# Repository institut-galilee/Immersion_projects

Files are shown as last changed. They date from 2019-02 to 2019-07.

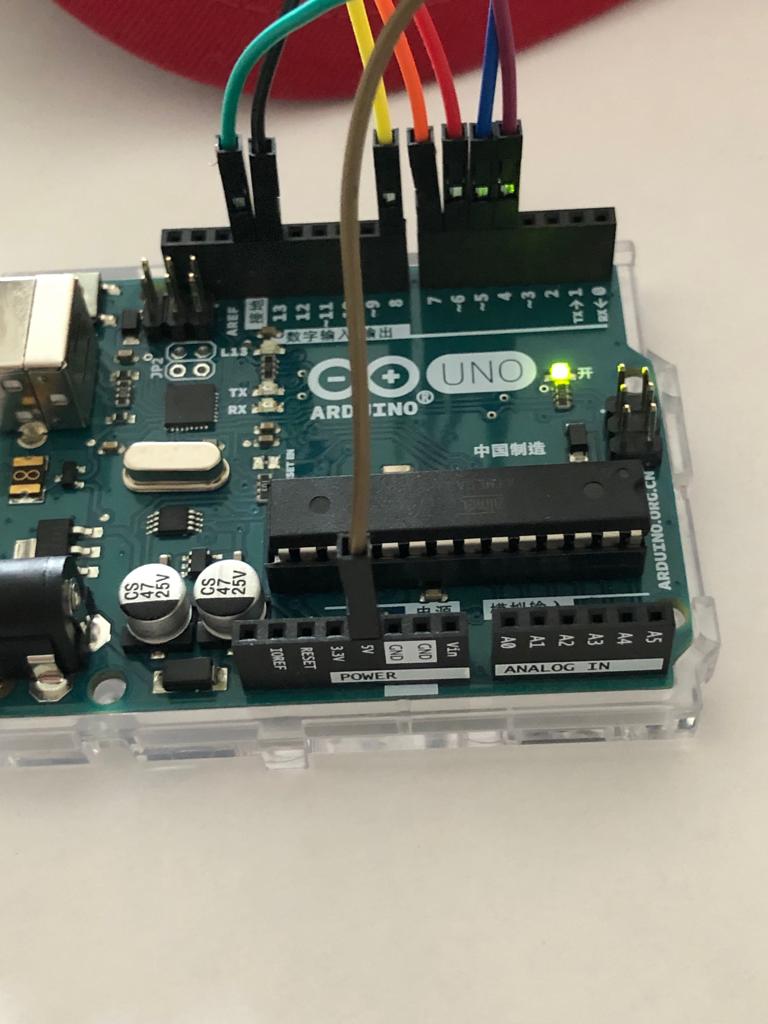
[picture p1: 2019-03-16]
Test Arduino/TCS3200/Montage 3.jpeg

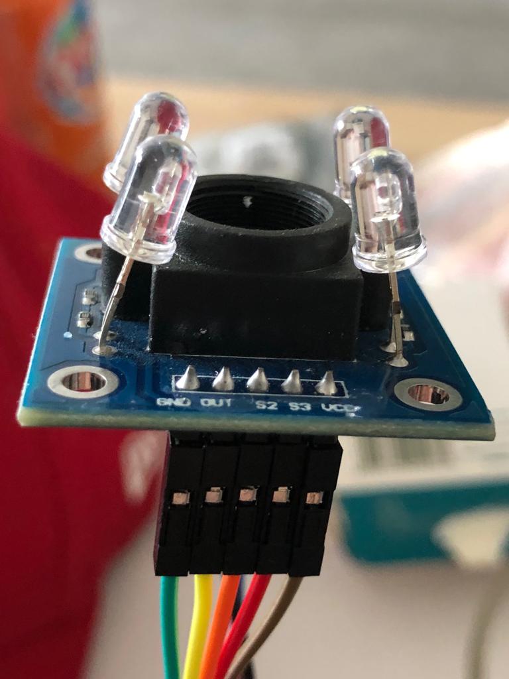
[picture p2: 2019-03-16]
Test Arduino/TCS3200/Montage 1.jpeg

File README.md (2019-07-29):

# Immersion_projects

## MEMBRES DE L'EQUIPE :
* Prenom: Heba Kaddouh [Hebakaddouh](https://github.com/Hebakaddouh)
  Email : heba.kaddouh@gmail.com
	  
* Prenom: Mohamed Ben Saad [Mohaabenz](https://github.com/Mohaabenz)
  Email : bensaad.mohamedamine@gmail.com

* Prenom: Jessy Colombo [Greyman93](https://github.com/Greyman93)
  Email : jessy.colombo31@gmail.com
	  
* Prenom: Khalid Barakat [Giitto](https://github.com/Giitto)
  Email : bckhalid@hotmail.fr
	  
## Nom du produit : Set-up Immersion 3.5D;

## Idée de base :

Le but de notre produit est une immersion dans une expérience multimédia s'approchant de la technologie de la 4DX à moindre coût.
Pour cela nous devons créer un set-up adaptable sur toutes les structures (télévisions, ordinateurs...). Le set-up est composé de la façon suivante :	
	
* LED : 
Il s'agit d'une bande LED connectée à votre smartphone en bluetooth que vous pourrez contrôler à votre guise. 
Mais la particularité de cette bande est son mode immersif : Elle s'adaptera automatiquement aux couleurs prédominantes,
que ce soit pour un jeu video, un film ou juste une image, l'expérience est garantie. 

* Fauteuil : 
Pour le moment, il s'agit d'une évolution du set-up qui permettrait une meilleure immersion quelque soit l'action. 
Pour cela deux enceintes connectées à votre périphérique en bluetooth ou en filaire ammeneront le son au plus proche de soit. 
Aux cotées de ces enceintes, nous allons intégrer des capteurs sonores liés à notre ESP32 qui permettront d'analyser le son. 
	Après analyse, des vibrations seront activé en fonction de l'action. Par exemple, si le bruit d'un balle de pistolet est entendu, 
	les moteurs vibrants situés sur le dos de la chaise s'activeronts. 

* Application : 
	L'application permettra de contrôler la bande LED. Elle pourra allumer ou éteindre la bande, activer les differents modes de 
celle-ci, augmenter ou diminuer la lumière ou bien changer la couleur de la bande.

En fonction de l'avancement du projet, nous pourrons ajouter d'autres amélioration, options, composant et objets connectés sur notre set-up

#### Composants suggerés :
Au départ, nous avons imaginé le set-up avec des composants facilement trouvable, manipulable et programmable.
* LED : ESP32, BANDE LED adressable, Capteurs couleur de lumière, cable USB, kit de connection (fil) ;
* Fauteuil : housse massage ou moteurs vibrants, enceinte bluetooth, ESP32, capteurs sonores; 

## TRAVAIL RÉALISÉ

### Analyse de l'éxistant
Au cours de notre analyse, nous avons pris connaissance de la plupart des technologies se rapprochant de nos objectifs. Pour la LED, les principales technologies sont intégré à l’intérieur même d'un téléviseur et d'autres si y connecte via HDMI ou USB. Toutes les recherches effectuées, nous ont amenés à la conclusion que notre méthode n'a pas encore été exploré. Il s'agit donc d'un défi que nous nous sommes fixé de réaliser. Le fauteuil quant à lui serait une version à moindre coût de la 4DX.

### Conception du prototype

#### LED
La conception de la LED a connu 3 versions :
* Version Alpha : Sur l'ESP32 les bibliothèques n’étaient pas compatibles nous sommes donc passé à l’Arduino pour avoir un prototype rapidement. Une fois la migration faite, la LED est capable de reconnaître les couleurs avec une reproduction approximative. 

* Version Beta : Le calibrage des couleurs est intégré afin de reproduire le plus fidèlement possible ce qui est émis par n'importe quel écran LED ou LCD (d'autres test pourront permettre une adaptation polyvalente).

* Version proto : Un ajout du Bluetooth liant application et micro-contrôleur afin de faciliter l'expérience utilisateur.  

#### Application

La conception de l'application a connu 2 versions :

* Version 0.1 : Une interface simple permettant de contrôler les couleurs de la LED via Bluetooth.

* Version 0.2 : Ajout d'une interface permettant le calibrage du capteur directement via l'application en suivant des intructions détaillées. Création de théme comme fondue, gradiant et guirlande.

### Perspectives

* La conception d'un fauteuil qui est encore en cours

* Passage à l'ESP32 qui serait un gain en coût, énergie et de taille.

* Permettre à l'utilisateur de mettre à jour son micro-contrôleur directement à partir de l'application

* Création d'un prototype ergonomique, compacte et facile d'installation.

* Création de trois modèles à budgets différents. Un modèle composé d'un capteur pour une immersion se basant sur la couleur prédominante. Un second avec quatre capteurs permettant une immersion plus poussée utilisant l'adressabilité de la LED et reproduisant les couleurs des coins de l’écran. Un dernier composé de tout les capteur nécessaire a l'immersion reproduisant les couleurs point à point.

* Une meilleure interface de l'application

* Rendre la calibration plus accessible à l'utilisateur

* D'autres objets garantissant une immersion toujours plus poussée

* Connecter l'ensemble du set-up à un assistant vocal

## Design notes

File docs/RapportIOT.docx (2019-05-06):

# Développement d’un objet connecté

# Immersion 3.5D

Réalisé par

KADDOUH Heba – BENSAAD Mohamed – COLOMBO Jessy – BARAKAT Khalid

Encadré par

M. Aomar OSMANI & M. Hamidi MASSINISSA

Master 1 Informatique – IOT Année 2018/2019

# Remerciements

Avant tout développement, nous profitons de ce rapport pour remercier ceux qui nous ont beaucoup appris et ceux qui ont eu la gentillesse de faire de cette expérience un moment profitable.

Nous tenons tout d’abord à remercier Monsieur Aomar OSMANI, qui nous a aidé et encadré tout au long du projet avec beaucoup de patience et de pédagogie. Ainsi que Monsieur Hamidi MASSINISSA, qui est resté disponible pour toutes nos questions et qui a su nous conseiller sur nos différents choix ainsi que sur la méthodologie à prendre.

# Présentation générale

## Présentation de notre application

Le but de notre produit est une immersion dans une expérience multimédia s'approchant de la technologie de la 4DX à moindre coût. Pour cela nous devons créer un set-up adaptable sur toutes les structures (télévisions, ordinateurs...). Le set-up est composé de la façon suivante :

- LED : Il s'agit d'une bande LED connectée à votre smartphone en Bluetooth que vous pourrez contrôler à votre guise. Mais la particularité de cette bande est son mode immersif : Elle s'adaptera automatiquement aux couleurs prédominantes, que ce soit pour un jeu vidéo, un film ou juste une image, l'expérience est garantie.
- Application : L'application permettra de contrôler la bande LED. Elle pourra allumer ou éteindre la bande, activer les différents modes de celle-ci, augmenter ou diminuer la lumière ou bien changer la couleur de la bande.
- Fauteuil : Pour le moment, il s'agit d'une évolution du set-up qui permettrait une meilleure immersion quel que soit l'action. Pour cela deux enceintes connectées à votre périphérique en Bluetooth ou en filaire amèneront le son au plus proche de soi. Aux cotées de ces enceintes, nous allons intégrer des capteurs sonores liés à notre ESP32 qui permettront d'analyser le son. Après analyse, des vibrations seront activé en fonction de l'action. Par exemple, si le bruit d’une balle de pistolet est entendu, les moteurs vibrants situés sur le dos de la chaise s'activeront.

La finalité du projet est la création d’un prototype fonctionnel pouvant par la suite s’améliorer avec de plus grands moyens financier et une focalisation exclusif sur celui-ci.

## Les enjeux

L’enjeu du projet qui nous a donné la motivation de le réaliser est d’ajouter une touche d’immersion dans le visionnage de diverses multimédias.

# Besoin de notre projet

Dans notre cahier de charges on a défini les besoins comme suite :

### LEDs connectées

Fonction | S’accorder en fonction de la couleur de l’écran TV
Objectif | S’éclairer de la couleur dominante de l’écran
Description | La bande LED sera munie d’un capteur de lumière qui lui transmettra les couleurs de l’écran afin qu’elle change de couleur
Contraintes | Le capteur de lumière doit être placé correctement par rapport à l’écran
Niveau de priorité | Haut

Fonction | S’accorder en fonction des couleurs définies par l’utilisateur
Objectif | S’éclairer de la couleur choisie par l’utilisateur
Description | La bande LED sera connectée à l’application et devra changer de couleur en fonction de ce qui est sélectionné dans l’application.
Contraintes
Niveau de priorité | Haut

### Application mobile

Fonction | Se connecter au périphérique
Objectif | Pouvoir contrôler la bande LED
Description | Le téléphone sera connecté en Bluetooth à la bande LED
Contraintes | La distance entre les deux objets connectés doit être raisonnable
Niveau de priorité | Haut

Fonction | Contrôler la bande LED à distance
Objectif | Permettre à l’utilisateur de changer la couleur de la bande
Description | L’application permettra de changer de couleur, allumer et éteindre les LEDs
Contraintes | L’application doit avoir la priorité sur le capteur de lumière
Niveau de priorité | Haut

### Housse connectée

Fonction | Capter le son de la TV
Objectif | Récupérer le signal sonore délivré par le son de la TV
Description | Le fauteuil récupérera le son
Contraintes | Nuisances sonores
Niveau de priorité | Moyen

Fonction | Réagir en fonction du son
Objectif | La housse devra vibrer en fonction de l’intensité du son
Description | Des moteurs vibrants intégrés à la housse réagiront en fonction du son
Contraintes
Niveau de priorité | Haut

# Conception architecturale

## Choix des langages de programmations

Notre application mobile est codée en JAVA pour les activités et classes, et en XML pour le design. Pour cela nous utilisons Android Studio.

Pour l’Arduino et le capteur, nous utilisons du C++ (.ino) à l’aide du logiciel Arduino IDE.

## Maquette de notre application

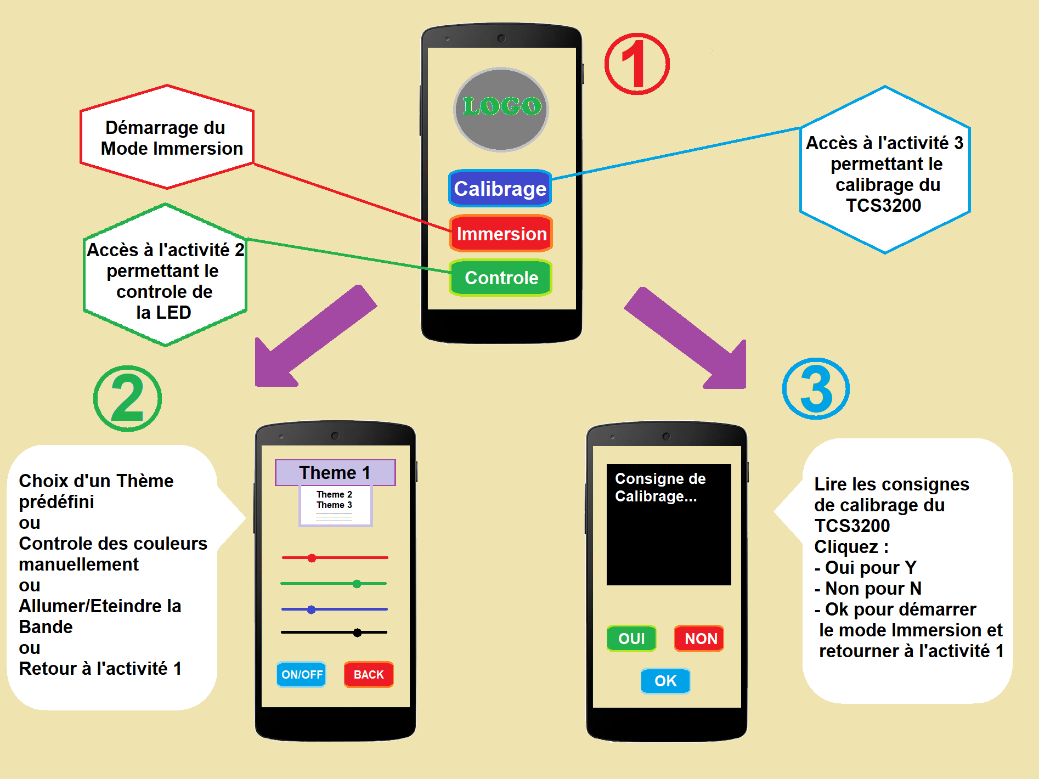
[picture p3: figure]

## Diagramme des cas d’utilisation

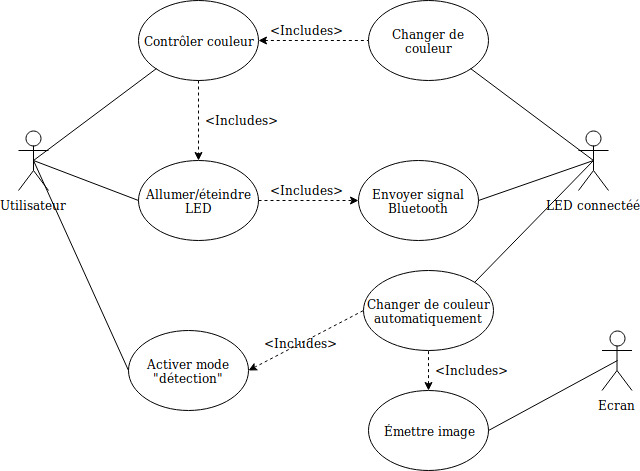
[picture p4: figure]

Un utilisateur pourra donc allumer et éteindre la LED, contrôler les couleurs seulement si la LED est allumée et activer le mode « détection » comportant son calibrage.

# Gestion de projet

## Planification et environnement de travail

Afin de réussir le projet et respecter la date du rendu, il nous a fallu une très bonne gestion et pour cela nous avons opté pour deux méthodes :

La première est l’organisation des membres de l’équipe, d’où le choix d’un chef de projet (Mohamed BEN SAAD), d’une équipe pour l’application mobile (Heba KADDOUH & Jessy COLOMBO) et d’une autre pour l’Arduino (Mohamed BEN SAAD & Khalid BARAKAT). Pour faciliter la communication nous avons créé un groupe WhatsApp qui nous permettait d’organiser des réunions (le jeudi matin ainsi que les mardis à 17h00 après le cours d’IOT, sans oublier, les créneaux du module), de s’entraider, de faire un échange d’informations et de faire une mise au point.

De plus, notre chargé de TD nous a conseillé de créer un compte GitHub afin de pouvoir suivre toutes les modifications du code et y avoir accès en cas de problème technique, que nous avons utilisé sans modération.

Nous avons mis en place sur GitHub dans l’onglet Projects, un planificateur de toutes les tâches que nous allons accomplir, que nous avons accomplies et que nous sommes en train d’accomplir. Ce planificateur nous a permis de se retrouver et de voir ce qu’il restait à faire. On peut aussi y retrouver les liens utiles, les composants et les logiciels utilisés.

## Répartition des tâches

Comme nous l’avons dans la partie précédente, nous avons réparti le travail en deux équipes.

Nous avons tous contribué à la conception architecturale en réalisant le diagramme de Gantt et du cas d’utilisation qu’on peut retrouver sur le GitHub, ainsi qu’à la rédaction du cahier des charges, de l’étude de l’existant, du rapport et de la conception du diaporama de présentation.

Pour avoir un meilleur aperçu du temps accordé pour chaque tâche, nous avons réalisé deux diagrammes : pour l’application mobile et pour l’Arduino.

## Diagramme de Gantt

Le diagramme de GANTT est un outil efficace permettant de générer une visualisation de l’avancement du projet. Il permet de donner une vue globale des tâches à réaliser et le du temps associé.

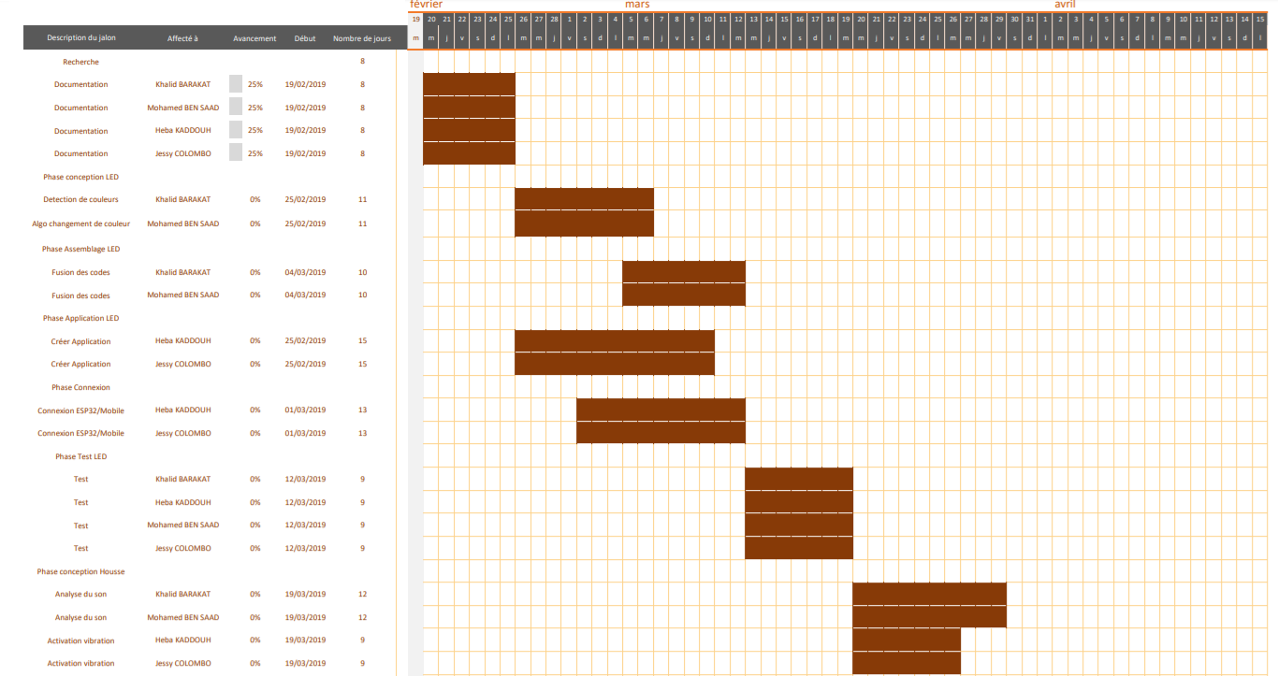
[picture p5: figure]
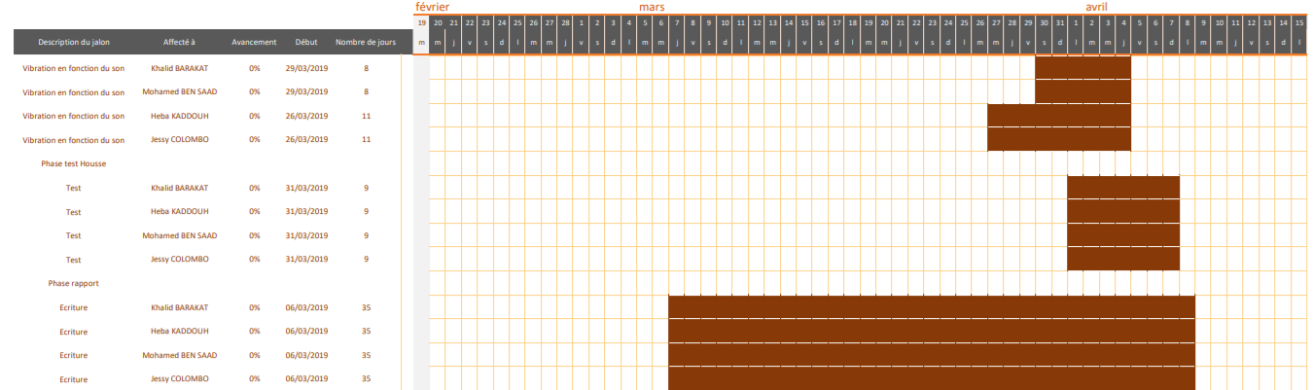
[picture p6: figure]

Nous avons réalisé le diagramme de Gant dans l’optique de l’accomplissement total du projet. Sauf que nous avions sous-estimé la complexité de celui-ci. Nous détaillerons tous nos changements par la suite.

# Développement du Set-Up

## Arduino

Au départ nous avons décidé d’utiliser une ESP32 pour notre projet. Malheureusement, après plusieurs essais de couplage de celle-ci avec notre capteur TCS3200, nous avons remarqué que l’architecture de l’ESP32 n’était pas compatible. Il aura fallu tout implémenter nous même pour l’adapter avec le capteur. Nous avons donc jugé plus judicieux de passer à une Arduino vu le temps qui nous était imparti. Ce choix n’a pas été anodin car nous avons trouvé plusieurs codes fonctionnels sur Arduino. Cela nous a permis de comprendre et de nous familiariser avec le TCS3200.

### Capteur TCS3200

Ces capteurs sont conçus pour détecter les couleurs d’objets et non celles d’un écran. Nous avons fait un pari risqué en le choisissant car nous ne savions pas s’il répondrait à nos attentes. Son faible prix nous a aidé à sauter le pas, nous réconfortant sur la faible perte qu’il aurait pu présenter.

Face droite Face Avant Face Gauche

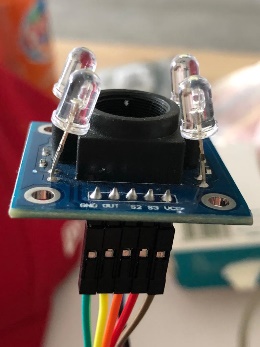
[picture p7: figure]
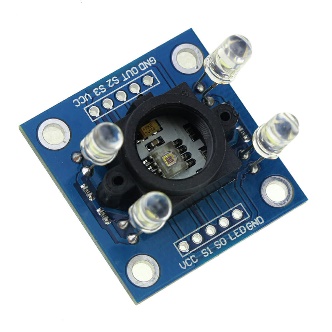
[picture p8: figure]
RÃ©sultat de recherche d'images pour "TCS3200"
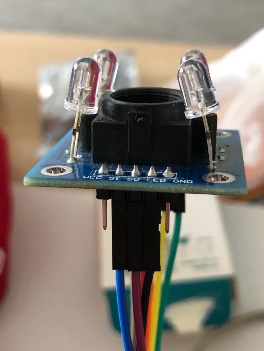
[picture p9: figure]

Notre premier objectif a été de faire fonctionner notre capteur avec l’Arduino. Le branchement a été rapidement maîtrisé grâce à quelques exemples trouvés au préalable.

Un fois le montage opérationnel, nous avons testé notre capteur avec plusieurs codes comme celui fourni avec le manuel électronique du TCS3200 et d’autres trouvés sur le Web. Cependant, comme le capteur n’est pas destiné aux écrans, la plupart de nos tests ont malheureusement échoué. À ce stade, nous avons réussi à reconnaitre les couleurs primaires (rouge, vert et bleu) avec des valeurs non conformes à nos attentes allant de -10 000 à 10 000. Nous devions remédier à ce problème et trouver une fonction qui nous permettrait de calibrer le capteur sur tous types d’écrans ainsi que de ramener les valeurs reçues entre 0 et 255. Nous avons essayé plusieurs modèles mathématiques pour moduler les valeurs captées, mais les codes utilisés n’étaient toujours pas dans l’intervalle voulu pour notre projet.

Après de nouvelles recherches, nous avons découvert une bibliothèque sur GitHub : https://github.com/blascarr/TCS3200-ColorSensor avec « TSC3200.h », implémenté spécialement pour le modèle de capteur que nous utilisons, incluant une fonction de calibrage optimal. Nous avons analysé cette bibliothèque pour pouvoir la modifier et l’adapter à nos nécessités. Une fois accordée à nos besoins, le résultat a répondu à toutes nos espérances. Pour calibrer le TCS3200, il suffit juste de poser le capteur sur l’écran avec la suite de couleur demandées lors de l’exécution de la fonction « calibration() ». Toutes les instructions sont affichées sur le Serial de l’Arduino (Terminal). Cependant, une source de lumière externe peut fausser celui-ci.

Par la suite, nous avons intégré la bande LED « Pixel Strip » à l’Arduino. A l’aide de sa bibliothèque originale « Adafruit_NeoPixel.h », nous avons pu lui envoyer les valeurs perçues par le capteur. Après quelques optimisations sur la synchronisation entre le TCS3200, l’Arduino et la bande LED, le Mode Immersion venait de voir le jour.

### Bluetooth HC-05

Le choix du HC-05 a été fait en fonction de son prix, de sa popularité et de sa bonne notation. À priori l’achat était sûr.

Il existe deux types de branchements, l’un est pour faire communiquer l’Arduino avec un autre objet connecté, le deuxième sert à paramétrer le module Bluetooth, par exemple donner un nouveau nom au HC-05 pour mieux l’identifier.

Branchement avec KEY pour configurer le Bluetooth

Pour vérifier que tout fonctionne comme il faut, il envoie « AT » vers l’Arduino. Si on obtient la réponse « OK », alors tout fonctionne et maintenant on peut utiliser les commandes de l’AT-MODE. Pour renommer le Bluetooth on rentre maintenant la commande AT-NAME = <nouveau_nom>.

Branchement normal pour communication

On envoie les données sur les ports TX/RX de l’Arduino. Cela facilité l’implémentation du code car il n’est plus nécessaire d’ouvrir un nouveau Serial pour transférer des données. Il faut noter que le TX du HC-05 se branche sur le RX de l’Arduino et le RX sur le TX. La communication est très importante pour le calibrage du TCS3200, étant donné que chaque modèle d’écran a des caractéristiques de couleur et de luminosité différente. Il faut bien suivre les instructions lors du calibrage du capteur pour ne pas avoir des erreurs sur les couleurs affichées ou leur intensité.

## Montage final

Une fois les deux parties précédentes accomplies, nous avons assemblé toutes les fonctionnalités dans un même code pouvant contrôler tous les composants de notre objet connecté ainsi que de toutes nouvelles fonctionnalités. C’est-à-dire, la communication Android/Arduino, le contrôle de la bande Led manuellement et les différents modes de celui-ci.

Voici le montage final de celui-ci :

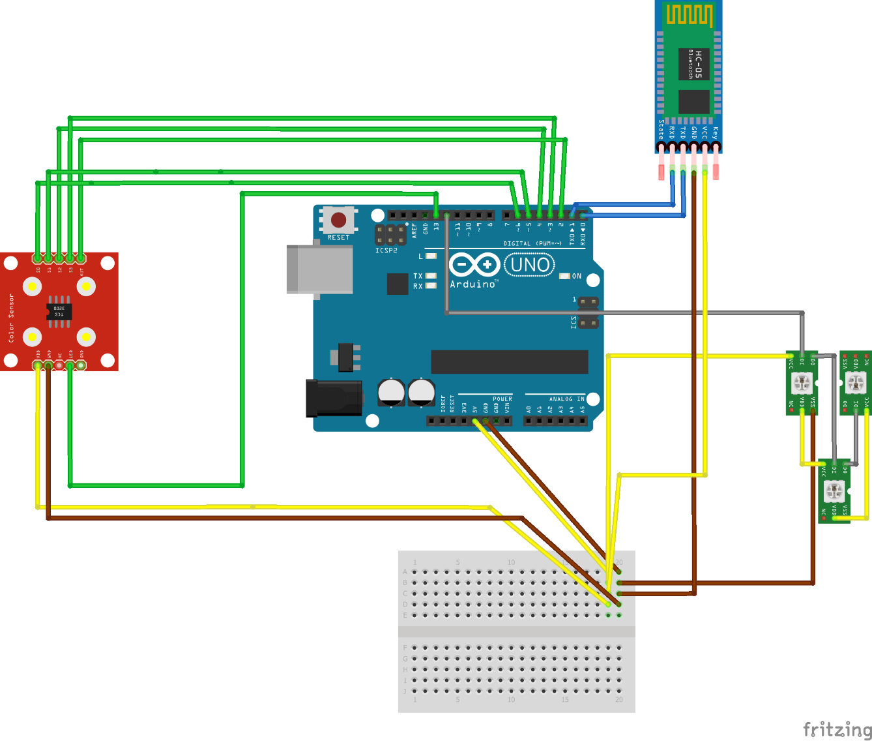
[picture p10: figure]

Composants | Port objet | Port Arduino
TCS3200 | VCC | 5V
| S3 | 3
| S2 | 4
| OUT | 2
| GND | GND
| S1 | 5
| S0 | 6
| LED | 13
HC-05 | GND | GND
| VCC | 5V
| RXD | TX 1
| TX | RX 0
LED | 5V | 5V
| GND | GND
| Din | 12

## Application mobile

### Page d’accueil

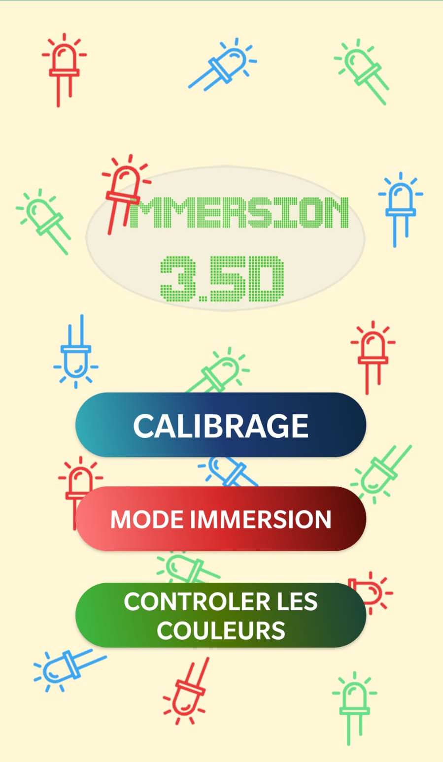
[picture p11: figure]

Lorsque l’utilisateur lance l’application, il se retrouve sur cette page et une connexion BluetoothSocket (bSocket) est lancée. La connexion Bluetooth est établie grâce à notre fonction « bluetooth_connect_device()». Si la connexion n’est pas établie, une fenêtre pop-up s’affiche « Vous n'êtes pas connecté avec l’équipement » et l’interface ne peut pas être utilisée. Et si la connexion Bluetooth n’est pas activée alors une demande d’activation de Bluetooth est demandé.

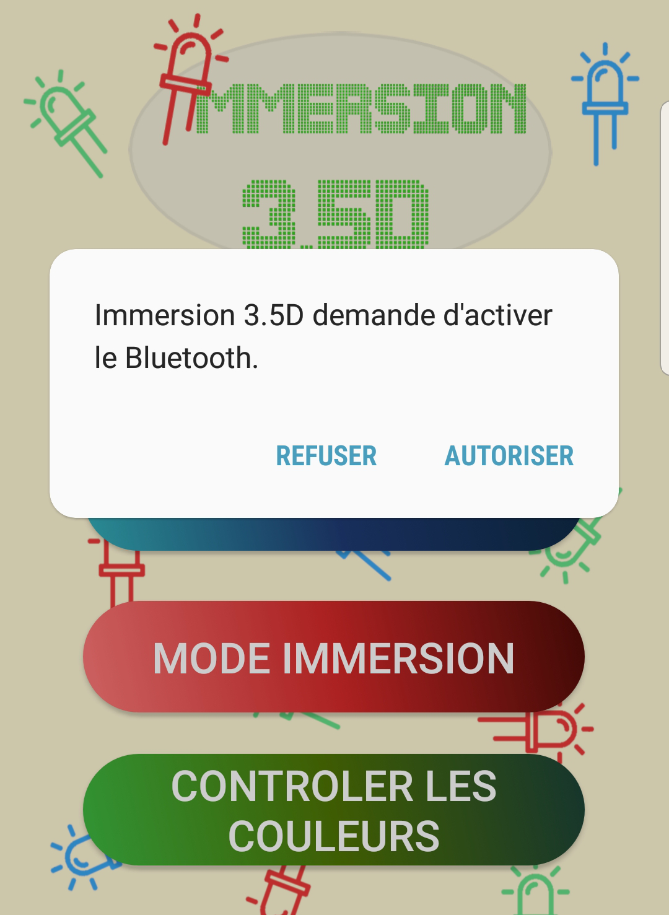
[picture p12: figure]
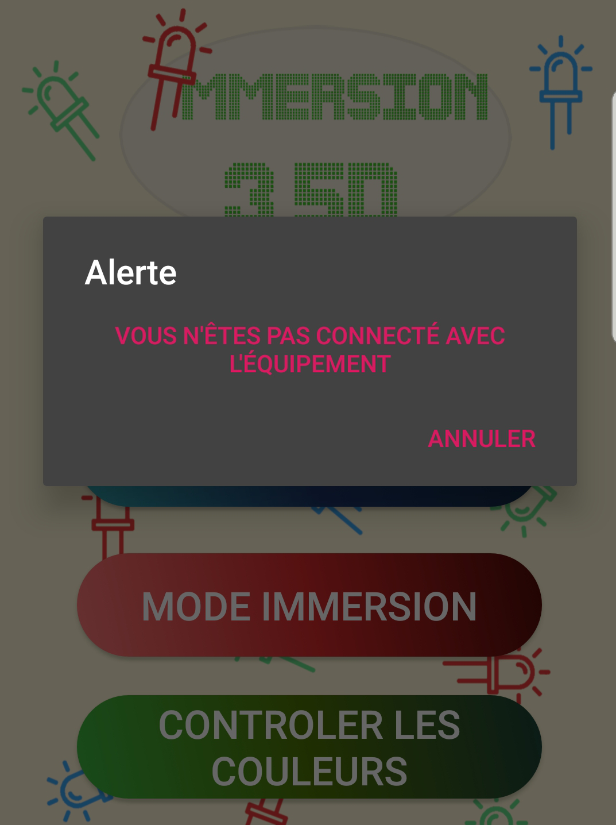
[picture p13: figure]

Au lancement de l’application, on envoie la lettre « O » par Bluetooth à l’Arduino qui permet de la mettre en mode On/Off.

A partir de cette page l’utilisateur peut, au click :

- Calibrer le TCS3200, en envoyant la lettre « C » par Bluetooth à l’Arduino et passe à la page de calibrage.
- Entrer en mode immersion en envoyant la lettre « I » par Bluetooth à l’Arduino et passe en mode immersion tout en restant sur cette page.
- Contrôler les couleurs en envoyant la lettre « T » par Bluetooth à l’Arduino et passe à l’interface de contrôle de la bande de leds.

L’envoi de caractères à l’Arduino via Bluetooth se fait comme suit : « bSocket.getOutputStream().write("O".getBytes()); »

### Page de calibrage

Lorsque l’on sélectionne le mode « calibrage », nous avons un champ de texte qui contient tout ce qui est renvoyé par l’Arduino et trois boutons :

- Oui, qui envoie la lettre « Y » à l’Arduino
- Non, qui envoie la lettre « N » à l’Arduino
- Mode immersion, qui envoie la lettre « O » à l’Arduino

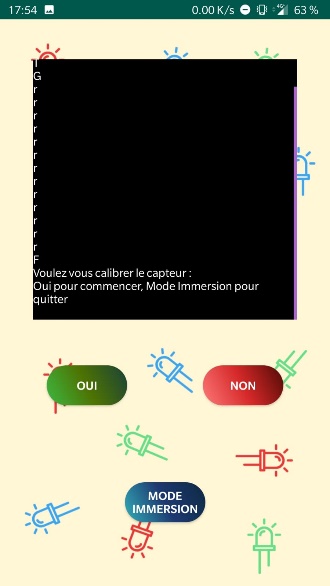
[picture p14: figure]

L’une des difficultés que nous avons eues avec cette page est de lire les données envoyées par l’Arduino. Pour pallier ce problème nous avons décidé de faire un thread qui reçoit, en continu et parallèlement du onCreate, les données grâce à la socket « bSocket » définie dans la page précédente. On dispose d’une boucle while permettant de lire les données envoyées par l’Arduino et de les afficher dans le champ de texte.

### Page de contrôle

En appuyant sur le bouton « contrôler les couleurs » depuis la page d’accueil, la page se transforme en un panneau de contrôle (représenté ci-dessous) contenant trois jauges pour configurer les couleurs selon le rouge, le vert et le bleu, et une quatrième jauge pour régler la luminosité. Grâce à la fonction « onProgressChanged », à chaque fois que l’utilisateur déplace un curseur nous stockons la valeur de la jauge que nous envoyons à l’Arduino.

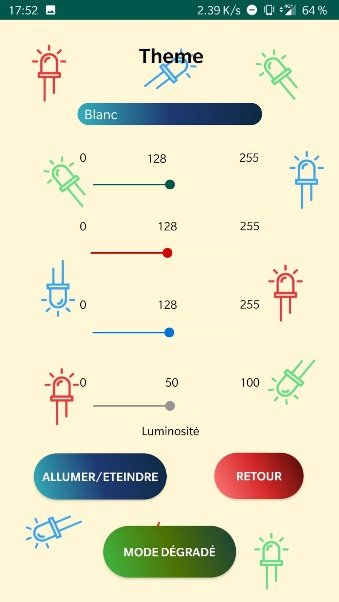
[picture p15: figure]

L’utilisateur a la possibilité de sélectionner des couleurs prédéfinies dans le menu déroulant se situant en haut de l’écran.

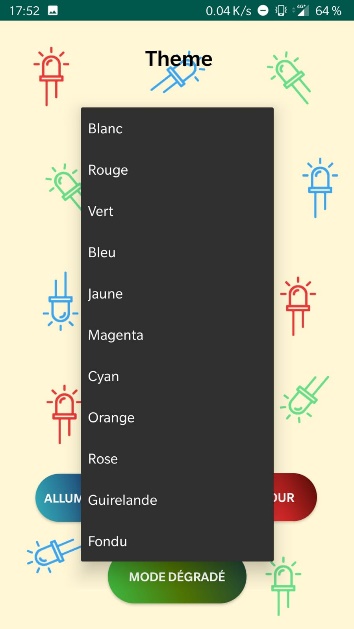
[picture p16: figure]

Lorsque l’utilisateur sélectionne un thème un caractère est envoyé à l’Arduino afin qu’il différencie les différents thèmes. Lorsque le thème « Guirlande » ou « Fondu » est activé, les jauges se désactivent. Pour chaque thème, on envoie le caractère « T » suivi des valeurs des couleurs sauf pour «Guirlande » et « fondu » :

- « G » pour guirlande
- « F » pour fondu

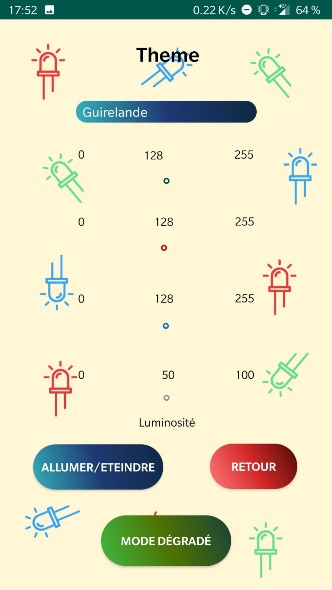
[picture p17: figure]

L’interface dispose également de trois boutons : « allumer/éteindre » pour allumer ou éteindre la bande de LEDS, « retour » pour revenir à la page d’accueil et « mode dégradé » menant à un nouveau panneau de contrôle servant cette fois-ci à configurer deux couleurs pour en faire le dégradé.

Là aussi des caractères spécifiques sont envoyés pour chaque bouton :

- « A » pour allumer
- « E » pour éteindre
- « D » pour le mode dégradé

### Mode dégradé

Le mode dégradé offre la possibilité de choisir deux couleurs, permettant ensuite à la bande de LEDS de s’illuminer du dégradé de la couleur n°1 à la couleur n°2. Comme pour la page précédente, on envoie les couleurs des différentes jauges ainsi que la luminosité à l’Arduino.

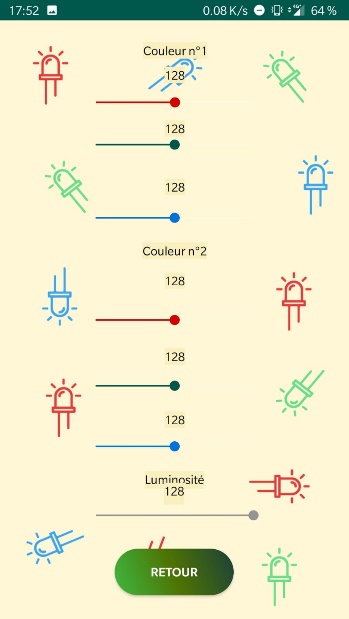
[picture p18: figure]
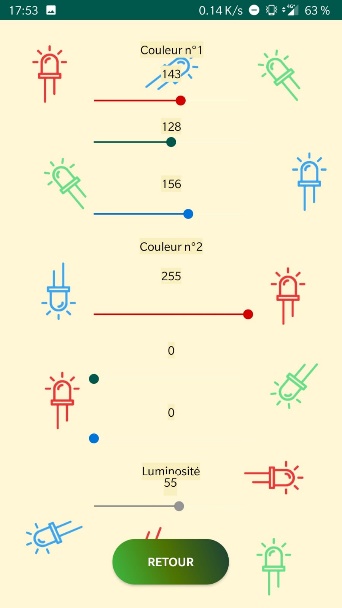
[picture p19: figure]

## Logo

Pour réaliser ce logo nous avons utilisé Paint3D.

# Contraintes/Difficultés

Choix de la carte électronique : Nous avons au début opté pour une ESP32 qui n’était pas compatible avec l’architecture de notre capteur.

Contraintes du capteur : environnement sombre et avoir juste l’écran comme source de lumières

Lecture et écriture de données : Nous avons eu du mal à :

- Lire les données envoyer par l’Arduino
- Envoyer des données à l’Arduino

Au vu de la complexité du projet et le manque de temps lié aux autres cours et projets, nous n’avons pas pu réaliser le fauteuil qui était une extension de notre projet.

# Bilan du projet

Ce projet était d’une grande envergure sur l’aspect fonctionnel et structurel mais il a été formateur et enrichissant pour nous, en effet l’idée du projet était assez compliquée et pour la mettre en œuvre il nous a fallu beaucoup de recherche et de persévérance. On a pu s’auto former sur les différents langages utilisés et mettre en pratique nos précédentes connaissances comme UML pour réaliser les différents diagrammes de conception. Ce projet était aussi une occasion de découvrir le vrai travail d’équipe.

# Annexe

## Mode d’emploi

Pour utiliser l’application, l’utilisateur doit d’abord appairer en Bluetooth son smartphone Android à l’Arduino. Une fois connecté il pourra effectuer les actions suivantes :

- Calibrer
- Contrôler les couleurs
- Lancer le mode automatique

Lorsque l’utilisateur clique sur « Calibrage », il reçoit une demande de confirmation. Si l’utilisateur clique sur « non », l’Arduino va charger les réglages stockés dans la mémoire. En revanche si l’utilisateur appuie sur le bouton « oui », le calibrage rapide commence, il faut alors mettre le capteur sur du Blanc et du Gris. En effet les écrans émettant toujours de la lumière. Le noir ne sera jamais vraiment noir donc un gris sombre est alors le meilleur choix. A chaque étape, une confirmation de l’utilisateur est requise dans le cas où il n’était pas prêt à capturer la couleur demandée. Une fois cela fait, un message s’affiche demandant à l’utilisateur s’il veut remplacer les réglages par défaut par la capture qui vient d’être effectuée. Pour finir la première étape, un nouveau message s’affiche demandant si l’utilisateur veut aussi calibrer les couleurs. S’il appuie sur « non », le calibrage prend fin et affiche les valeurs enregistrées. A l’opposé si l’utilisateur lance la deuxième étape, des indications vont s’afficher pour calibrer sur les couleurs suivantes : bleu, jaune, marron, orange, rouge et vert, en suivant la même procédure que lors de la première étape. Pour terminer, un dernier message demande si l’utilisateur veut sauvegarder le calibrage dans la mémoire. Une fois la réponse reçue, sur le terminal sont affichées les valeurs capturées de chaque couleur lors du calibrage. Les valeurs affichés pour une couleur sont d’abord le rouge puis le vert puis le bleu et enfin la luminosité.

Pour un bon calibrage voici une table avec les intervalles de valeurs à obtenir pour chaque couleur :

| Rouge | Vert | Bleu
Blanc | > 250 | > 250 | > 250
Noir | < 15 | < 15 | < 15
Jaune | > 245 | > 245 | < 30
Orange | > 220 | 100 - 200 | < 75
Rouge | > 220 | < 40 | < 40
Vert | < 40 | > 220 | < 40
Bleu | < 40 | < 40 | > 220
Marron | 100 - 180 | < 90 | < 10

Lorsque l’utilisateur clique sur « Mode immersion », la bande LED change de couleur en fonction de celle perçue par le capteur. L’utilisateur aura juste à placer le capteur devant un écran.

Lorsque l’utilisateur clique sur « Contrôler les couleurs », il est amené sur une autre page qui lui permet de :

- Choisir des thèmes en cliquant sur le menu déroulant
- Changer les couleurs et la luminosité de la LED grâce aux jauges
- Eteindre ou allumer la LED en cliquant sur « Allumer/Eteindre »
- Retourner sur la première page en cliquant sur « Retour »
- Basculer en « Mode dégradé » qui nous amène sur une nouvelle page où il configurera alors deux couleurs.

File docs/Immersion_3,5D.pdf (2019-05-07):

# IMMERSION

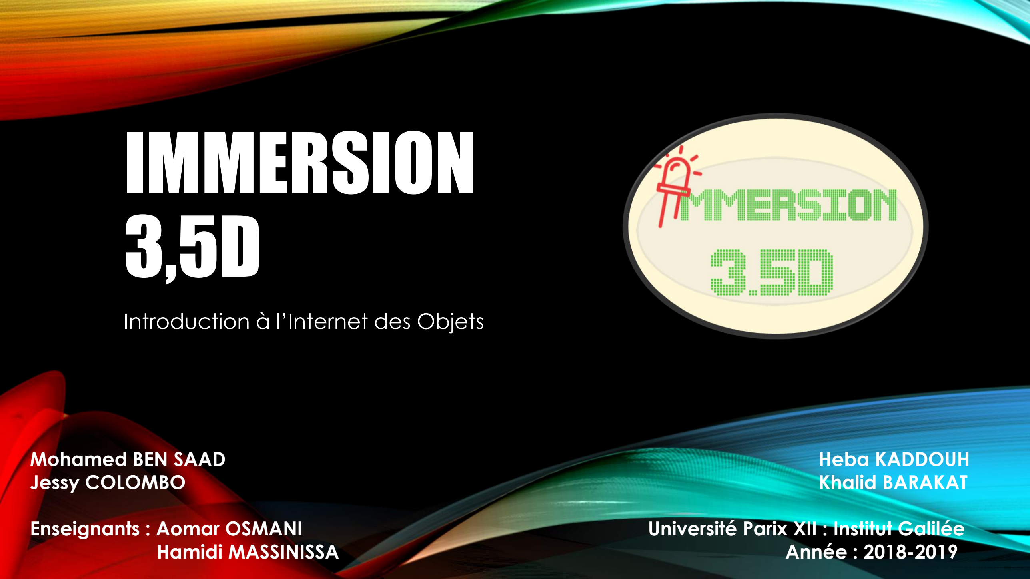
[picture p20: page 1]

3,5D

Introduction à l’Internet des Objets

Mohamed BEN SAAD | Heba KADDOUH
Jessy COLOMBO | Khalid BARAKAT
Enseignants : Aomar OSMANI | Université Parix XII : Institut Galilée
Hamidi MASSINISSA | Année : 2018-2019

# SOMMAIRE

- Présentation du projet
- Plan d’action
- Arduino
- Application
- Calibrage du capteur (Mode calibrage)
- Mode Immersion
- Contrôle des couleurs (Mode contrôle)
- Conclusion

# PRÉSENTATION DU PROJET

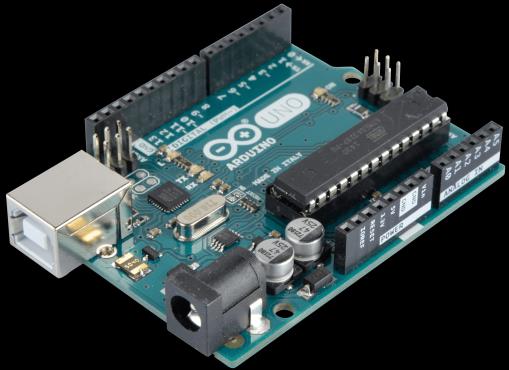
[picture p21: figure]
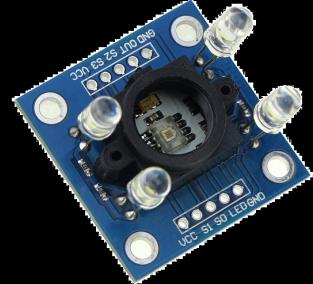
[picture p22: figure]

Set-up d’immersion avec son application Android
- 1 carte Arduino UNO
- 1 capteur de couleurs TCS3200
- 1 bande de 60 leds
- 1 connecteur Bluetooth HC-05
- 1 smartphone Android

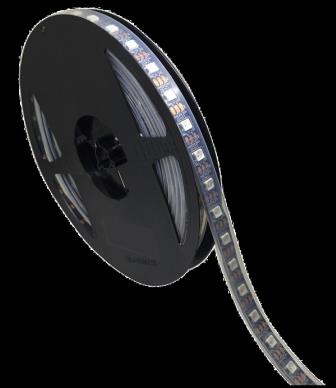
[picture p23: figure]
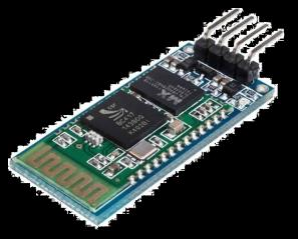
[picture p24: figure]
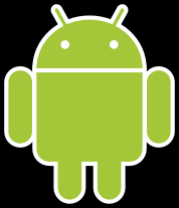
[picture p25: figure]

# PLAN D’ACTION

Périodes | Team | Jessy et Heba | Khalid et Mohamed

Semaine

1 & 2 | Taches | Familiarisation avec l’environnement
| | Android Studio | Manipulation Arduino et capteur

Semaine
3 & 4 | | Connexion Bluetooth Android | Couplage Capteur/Bande LED

Semaine

### 5 à 8

Fusion | | Intégration Bluetooth/Arduino
Modes | Contrôle LED | Calibrage | Immersion
Final | | Débuggage et optimisation du code
| Rapport | Vidéo | PowerPoint

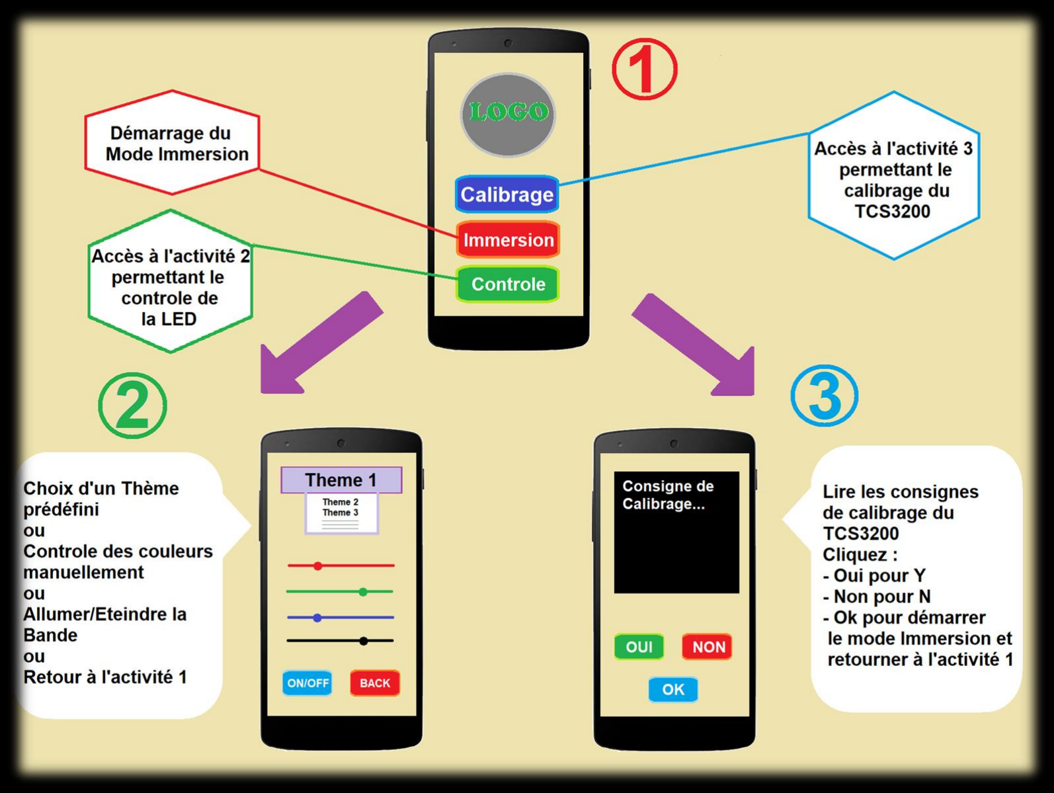
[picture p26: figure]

# APPLICATION

- Android Studio
- JAVA
- XML


# ARDUINO

- Rôle
- Capteur TCS3200
- Bande LED
- Bluetooth HC-05

# APPLICATION


- Bluetooth
- Modes
- Envoi
- Réception

Envoi

Réception

# CALIBRAGE DU CAPTEUR


- Noir et Blanc
- Couleurs primaires
- Autres couleurs
- Contraintes

# MODE IMMERSION


- Synchronisation
- Immersion
- Qualités/Défauts
- Prévisions

# CONTRÔLE DES COULEURS


- Sélection de thème
- Commande manuelle
- Envoi instantané
- Allumer/Eteindre
- Retour Accueil
- Mode dégradé

# CONCLUSION

- Gestion d’une équipe et du temps
- Communication basée sur l’écoute active
- Recherche efficace et apprentissage autodidactique
- Gestion complète d’un projet

# MERCI

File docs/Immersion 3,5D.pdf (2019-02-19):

# Cahier des Charges IOT

# Nom du projet : Immersion 3.5D

2018/2019

Heba Kaddouh | Mohamed Ben Saad |Jessy Colombo |Khalid Barakat

# Table des matières

# Présentation du projet

## Immersion 3.5D

## Contexte

De plus en plus de gadgets ont envahi notre domicile. La technologie ne cesse d’améliorer notre quotidien. Que ce soit au niveau du pratique, de l’utile ou du confort, nous cherchons toujours à être à jour et à nous familiariser avec tous ces objets connectés.

La venue de la VR (Virtual Reality) a donné naissance à de toutes nouvelles sensations. Comme l’immersion augmentée avec la 4DX au cinéma ou bien le PlayStation VR de la marque Sony. Mais toutes ces nouveautés ont un coût considérable pour une personne à revenu moyen.

Taux d’équipement par foyer :


Observatoire de l’équipement audiovisuel des foyers en France Métropolitaine Résultat 2017

## Objectifs

Un setup d’immersion à moindre coût, ouvert à tous et modulable aurait sa place sur le marché du consommateur moyen.

Pour le moment, l’ajout d’une bande LEDs autonome connectée est ce qui semble être le plus approprié pour augmenter l’immersion. Elle permettra d’ajouter une lumière ambiante autour de n’importe quel écran. Sa fonction principale est de changer de couleur en fonction de l’image émise par celui-ci et en temps réel. L’achat d’un nouvel écran ne sera donc pas une nécessité.

Une fois le premier objet connecté terminé, le set-up proposera également une housse vibrante. Cette housse sera un complément à n’importe quel fauteuil. Ses particularités seront deux enceintes Bluetooth amenant le son près de l’utilisateur ainsi qu’émettre des vibrations en fonction de l’action.

Cette configuration pourra évoluer et laisser place à d’autres objets, tous connectés à une application mobile centrale.

L’objectif est d’obtenir une immersion satisfaisante, agréable, sans nuisances, de qualité et à prix raisonnable.

## Ecosystème

Comme nous l’avons cité dans la présentation, les objets de notre set-up existent déjà sur le marché avec un coût élevé. L’Ambilight (Phillips) serait la première alternative à notre bande de LED mais elle est intégrée directement dans le téléviseur. Le DreamScreen Kit est la technologie la plus proche de la LED autonome que nous concevons, mais celle si utilise une connexion directe avec l’écran avec une entrée et sortie d’un port HDMI. Son coût est de l’ordre de 170 euros. Sur le marché étranger, nous avons toute sorte de bandes LEDs équivalentes à la précédente, fonctionnant cette fois-ci à l’aide d’une connexion USB liée à l’écran. Ce que nous voulons amener est une connexion sans fils.

Les retours sur l’Ambilight ont été très positifs d’après plusieurs enquêtes. Pour le visionnage d’un film, d’une série ou lors d’une partie de jeu vidéo, l’immersion a été concluante. Cette technologie a obtenu une moyenne de 4,2 sur 5, ce qui nous laisse penser à une future propagation dans chaque foyer.

Pour la housse connectée, la 4DX est la technologie la plus poussée sur le marché. Le XROCKER Siège Gaming Sony Infinity est le fauteuil complet intégrant les fonctionnalités recherchées c’est-à-dire les enceintes et les vibrations. En moyenne, le prix de ce genre de fauteuil est de 500 euros.

Sur le marché il n’existe pas de housse vendue séparément du fauteuil capable de réaliser les fonctions voulues. Notre housse pourra s’intégrer sur n’importe quel fauteuil approprié, d’où la réduction de coût en enlevant le prix du siège.

## Le périmètre

Le set-up d’immersion 3,5D à pour cible tous les foyers, mais pour le moment nous visons le marché français. Une fois que nous aurons une configuration avec plus d’objets, nous pourrons envisager le marché européen puis l’international.

# Expression des besoins

Nous aurons besoin d’une bande de LEDs, une carte ESP32, des fils, un capteur de lumière. Nous devrons aussi développer une application mobile (Android) qui servira d’interface de contrôle de la bande LED. On pourra également ajouter une housse de siège à vibration qui sera connectée.

## Besoins fonctionnels

LEDs connectées

Fonction | S’accorder en fonction de la couleur de l’écran TV
Objectif | S’éclairer de la couleur dominante de l’écran
Description | La bande LED sera munie d’un capteur de lumière qui lui transmettra les couleurs de l’écran afin qu’elle change de couleur
Contraintes | Le capteur de lumière doit être placé correctement par rapport à l’écran
Niveau de priorité | Haut

Fonction | S’accorder en fonction des couleurs définies par l’utilisateur
Objectif | S’éclairer de la couleur choisie par l’utilisateur
Description | La bande LED sera connectée à l’application et devra changer de couleur en fonction de ce qui est sélectionné dans l’application.

Contraintes

Niveau de priorité | Haut

Housse connectée

Fonction | Capter le son de la TV
Objectif | Récupérer le signal sonore délivré par le son de la TV
Description | Le fauteuil récupérera le son
Contraintes | Nuisances sonores
Niveau de priorité | Moyen
Fonction | Réagir en fonction du son
Objectif | La housse devra vibrer en fonction de l’intensité du son
Description | Des moteurs vibrants intégrés à la housse réagiront en fonction du son

Contraintes

Niveau de priorité | Haut

Application mobile

Fonction | Se connecter au périphérique
Objectif | Pouvoir contrôler la bande LED
Description | Le téléphone sera connecté en Bluetooth à la bande LED
Contraintes | La distance entre les deux objets connectés doit être raisonnable
Niveau de priorité | Haut
Fonction | Contrôler la bande LED à distance
Objectif | Permettre à l’utilisateur de changer la couleur de la bande
Description | L’application permettra de changer de couleur, allumer et éteindre les LEDs
Contraintes | L’application doit avoir la priorité sur le capteur de lumière
Niveau de priorité | Haut

## Diagramme UML

Use Case


## Analyse de la complexité

ID | Objectif | Description | Complexité
1 | Composant | L’achat de l’ensembles composants | 1
2 | Conception de la LED | La LED doit être commandable par l’utilisateur mais la principale fonction est la détection de la couleur émis par un écran | 6
3 | Conception de la housse | La housse doit vibrer en fonction du son émis par les enceintes Bluetooth | 8
4 | Application Mobile | L’application doit permettre le contrôle de la LED | 4

# Contraintes / Difficultés

## Coûts du matériel

Le coût total du projet devra être relativement bas et pas supérieur à 25 euros pour les LEDs autonomes et pas au-delà de 50 euros pour le siège connecté.

Composant : LED | Cout

Composant :
Housse

Cout

Bande LED | ≈ 5€
Housse fauteuil | ≈ 12€
Enceinte Bluetooth | ≈ 10€
ESP32 | ≈ 8€ | ESP32 | ≈ 8€
Breadboard | ≈ 0.5€ | Breadboard | ≈ 0.5€
Capteur Sonore | ≈ 8€
Moteur vibrant | ≈ 10€
Fils de connexion | ≈ 2€ | Fils de connexion | ≈ 2€
Capteur TCS3200 | ≈ 8€
Total | ≈ 25€ | Total | ≈ 50€

L’application mobile sera totalement gratuite.

## Coûts humain

Le projet est réalisé à 100% par les membres du groupe.

Ce coût est calculé en fonction du temps estimé pour accomplir la tâche ainsi que la difficulté, sur une échelle de 1 à 10.

LED autonome

Coût | Housse | Coût

Commander
composants

1

Commander
composants

1

Programmer
l’ESP32 (avec
l’apprentissage du
langage)

8

Faire en sorte que
l’ESP32 reconnaisse
le son émis

9

Assemblage et installation des composants | 2 | Programmer l’ESP32 pour avoir des vibrations en fonction du son | 7
Réalisation de l’application (avec l’apprentissage du langage) | 7 | Assemblage et installation des composants | 4

Faire en sorte que
l’application se
connecte en
Bluetooth à l’esp32

5

La partie la plus difficile sera donc la partie programmation car nous devons apprendre un nouveau langage. La réalisation de la housse sera, selon nous, la partie la plus compliquée et celle qui nous demandera le plus de temps.

## Délai

Le projet devra être livré avant le 2 avril 2019.

## Logiciels

Les logiciels que nous utiliserons sont : Arduino IDE pour la partie programmation de nos objets connectés et Android Studio pour une application simple.

## Langage

A priori les langages les plus adaptés à nos besoins sont le Java et le langage propre à Arduino

## Technique

Comprendre comment fonctionne le langage Arduino pour pouvoir coder l'ESP32.

## Sécurité

Les LEDs doivent éviter de troubler la vue des utilisateurs.

# Déroulement du projet

## Diagramme de Gantt / Prévisions


Le projet se fera en plusieurs phases. Tout d’abord la LED. Une première phase qui portera sur de la recherche des technologies utilisées qui nous orientera sur les choix que nous prendrons au fil de l’avancement. Nous avons pensé méthodiquement à une répartition des tâches en parallèle pour chaque étape. Une phase de conception et de configuration est primordiale pour la suite des opérations. L’application mobile se fera tout au long de celles-ci. L’établissement d’une connexion entre nos composants nous aidera à effectuer tous nos tests. C’est seulement une fois la LED terminée que nous pourrons entamer la conception de la housse vibrante.

Il nous semble nécessaire de rédiger un rapport régulier pour envisager de terminer dans le délai imparti.

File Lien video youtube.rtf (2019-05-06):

Cliquez pour voir la video : https://www.youtube.com/watch?v=F6XeG3sRFKY&feature=youtu.be

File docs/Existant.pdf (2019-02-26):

# Existant

# Nom du projet: Immersion 3.5D

2018/2019

Heba Kaddouh | Mohamed Ben Saad |Jessy Colombo |Khalid Barakat

# Table des matières

# Introduction

L’immersion est au goût du jour. La technologie 3D était la première dans le domaine. Aujourd’hui, on ne compte plus toutes les technologies autour de l’immersion. Que ce soit la réalité augmentée maitrisée grandement par HTC et Sony, ou bien la 4DX de plus en plus en vogue dans les cinémas aux quatre coins du globe.

Le but de notre analyse, est d’apporter une touche d’accessibilité aux technologies d’immersion lumineuse et corporelle. Il ne s’agira pas de 3D ou de 4DX, mais de s’en approcher afin de les proposer à un public plus large.

# Analyse de l’existant

## LEDS connectée

Sur le marché nous pouvons trouver différents types d’utilisations de LEDs, que ce soit pour éclairer une pièce ou pour accompagner l’image projetée sur notre écran. Ces utilisations se font par le biais de technologies avec ou sans-fils. Voici une analyse de ce qui est déjà présent sur le marché, qui nous aidera pour sélectionner les technologies que nous utiliserons pour notre projet.

- L’Ambilight : Ensemble de LEDs intégrées au téléviseur. Cette technologie est brevetée, donc disponible seulement sur les téléviseurs Philips® dont elle est vendue avec.
- Le DreamScreen : Kit de LEDs à mettre autour d’un écran
- Le Lightpack : dispositif de LEDs pour PC

Note
/10
Nom | Marque | Fonctionnalités | Coût € | Public visé
10 | Ambilight | Philips | -Projection des couleurs de l’écran
| | | -Projection de l’image de l’écran

500 à
4500

Grand publics

8 | DreamScreen | DreamScreen | -Projection de l’image sur l’écran
| | | -Possibilité de contrôle par une application
150 à 190 | Grand publics
6 | Lightpack | Développeurs indépendants
| | OpenSource

-Projection de l’image sur l’écran

-Possibilité de contrôle par une application

-Choix de différentes
configurations

-Possibilité d’assembler
avec d’autres Lightpacks en les synchronisant
79 | Grand publics
Ali express | Multiple | Inconnu | 35 | Grand public

## Fauteuil Vibrant

Note /10 | Nom | Marque | Fonctionnalités | Coût € | Public visé
20 | 4DX | CJ 4DPLEX | - Vibrations, Vent, Tempête, Pluie, Odeur, Neige, Mouvement, Eclair, Eau, Chatouilles, Air, Bulles, Brouillard, Chaleur | 20 (Séance de cinéma) | Cinéma

10

X Rocker
Sony
Infiniti+

Sony

- Bluetooth embarqué
- Connexion sans fil
- Haut-parleurs intégrés
au niveau de la tête et
de l’assise
- Caisson de basses au
niveau du dos
- Vibrations
- Panneau de contrôle
intégré
- Port USB, prise Jack et
prise casques intégrés
- Prend en charge les
consoles Playstation
- Prend en charge les
appareils mobiles

350 Gamers

5

Fauteuil
vibrant Mod-It
- Bluetooth embarqué
- Connexion sans fil
- Haut-parleurs
- Vibrations
- Prise jack
- Pliable

200

Grand
publics

# Etat de l’art

Ici nous avons deux technologies d’immersion visées. Tout d’abord une bande de LEDs créant une lumière ambiante autour d’un écran et imitant les couleurs prédominantes de celui-ci. Puis, une housse de fauteuil incluant deux enceintes et faisant ressentir de petites vibrations en fonction de l’intensité de l’action.

## LEDs

L’Ambilight

L’Ambilight est une technologie créée par Phillips intégrée à une gamme de ses téléviseurs (Ambilux). Cette exclusivité existe depuis 2002, elle consiste à reproduire le code couleur de l’image affiché par un écran. L’ensemble des couleurs affichées à l’écran sont retranscrite de façon dynamique. Le principe paraît simple, mais a nécessité de longues recherches pour en devenir sa marque de fabrique. Elle a donné naissance à trois types d’Ambilights :

- Ambilight Spectra 2 : LED en position face arrière gauche et droite de l’écran
- Ambilight Spectra 3 : LED en position face arrière dessus, gauche et droite de l’écran
- Ambilight Projection : projecteur à la même position que le Spectra 3


L’Ambilght Projection est à un tout autre niveau car elle étend l’image de l’écran sur le mur.

Le concept Ambilight en général est breveté, et cette nouvelle technologie relève encore du brevet existant concernant les téléviseurs Philips. En outre, de nouveaux brevets ont été déposés afin de protéger les innovations spécifiques concernant la projection. Cela ne signifie qu’aucune autre marque ne dispose de la fonction Ambilight ou Ambilight Projection. Sa consommation électrique maximale est de 35 W. À titre de comparaison, un système Ambilight 3 côtés sur un téléviseur de 65" consommerait 20 W au maximum. Le flux total est légèrement supérieur à celui d'un spectre ambilight 65" habituel : 350 lm. Le nombre d'heures de fonctionnement du projecteur utilisé pour la fonction Ambilight Projection est identique à celui du système Ambilight classique. Les brevets de la marque nous empêchent de connaitre les détails des technologies utilisées.

Le DreamScreen

Le DreamScreen Kit est un semi-clone de l’ambilight développé par un couple américain Rakesh et Kate Reddy. Cette fois-ci les LEDs sont intégrées dans un dispositif programmé pour réagir de façon à s’approcher de l’Ambilght de Phillips. L’éclairage dit « intelligent » réagit avec la couleur des pixels des écrans à 60 images par seconde. Lancés sur Kickstarter 2017, les DreamScreen HD suivent le courant de la haute définition et enrichissent les films, jeux vidéo et séries préférées de personnes dans le monde entier avec à la technologie de rétroéclairage réactif. Le dispositif utilise la technologie de communication Wi-Fi pour communiquer avec votre smart TV et retransmettre en lumière les données relatives aux couleurs. Le contrôle et la sélection des modes de fonctionnement du smartphone s’effectuent à partir d’une application mobile.

À partir de celle-ci, vous avez la possibilité de contrôler la luminosité, le contraste et la saturation des couleurs des lumières. Elle sert de plateforme de contrôle passant d’un mode à un autre. Avec le mode vidéo, vous pourrez harmoniser les couleurs de vos contenus vidéo avec l’éclairage ambiant. D’autre part, le mode musique vous permet d’accompagner vos chansons de jeux de lumière. Et enfin, un mode « ambient lighting » pour créer une atmosphère à partir de l’éclairage dynamique.


Le système dispose de 3 entrées HDMI pour vous permettre de changer de source vidéo tout en conservant l’éclairage d’ambiance. Il dispose également d’une prise jack pour y associer directement vos contenus musicaux et s’alimente à partir d’un port USB

CARACTÉRISTIQUES

- Taille classique: pour les TV de 32" à 45" (81cm à 114cm)
- Taille méga: pour les TV de 45" à 65" (114cm à 165cm)
- Taille Xtreme: pour les TV de 65" à 80" (165cm à 203cm)
- Connexion WiFi
- 3 entrées HDMI : 1,4 avec HDCP supporte jusqu’à 1080 P 60 Hz et contenu 3D
- Prise jack audio
- Alimentation Micro USB
- 4 visualiseurs audio différents

Autres projets indépendants

Disponible depuis 2004, l’Ambilight n’est malheureusement disponible que sur les TV de la marque Phillips. Ce qui a donné lieu à de nombreux projets indépendants tentant de reproduire cet effet à base d’Arduino, Raspberry Pi, et quelques rubans LEDs. La plupart sont disponibles sur GitHub et nous en avons sélectionné l’un d’entre eux.

L’année dernière l’un de ces projets a été mis sur le site de financement participatif Kickstarter : LightPack. Un projet Open Source qui a d’ailleurs très bien fonctionné, puisqu’il a reçu un demi-million de dollars de financement, le double de ce dont il avait besoin !

Lien Github : https://github.com/Atarity/Lightpack-docs

Ce système fonctionne de la même façon que le Dreamscreen mais seulement sur PC. Lightpack se compose d'une carte mère, de voyants RVB supplémentaires, d'un micrologiciel permettant de gérer le matériel et du logiciel de capture d'image Prismatik installé sur un PC. Le logiciel calcule une couleur moyenne de l'image affichée à l'écran pour chaque zone de capture correspondant à une LED. Après cela, les données des couleurs sont transférées par USB vers la carte mère, où le micrologiciel, après les avoir traitées, allume la LED définie par la couleur définie. Ce processus se répète plusieurs dizaines de fois par seconde.

Lightpack utilise un logiciel nommé Prismatik. Une fois installé sur le PC, il résout deux tâches: la capture d’images et l’accès aux paramètres de l’appareil.

La capture d'image est un screenshot d’une zone de l’écran afin de déterminer sa couleur moyenne et de transférer les données la concernant au périphérique. Le nombre de zones capturées est identique à celui des LEDs. Le logiciel doit donc effectuer cette opération 10 fois par compte de 1 minuterie. Le nombre de comptes dépend des paramètres, mais il ne devrait pas être moins de 15-20 par seconde en moyenne.


Voici les composants de LightPack :


Les autres projets que nous avons trouvés sur Github fonctionnent d’une même façon mais se limite au PC. L’étude de l’art de tous ces projets demandera une analyse complète de leurs codes.

Lien Github : https://github.com/search?q=Ambilight

## Housse vibrante

4DX

La 4DX est une technologie cinématographique détenue et développée par la société sud-coréenne CJ 4DPLEX et est déjà présente dans une trentaine de pays. Cette technologie existe depuis 2009, elle consiste à améliorer les effets d’immersion en jouant sur nos sensations, en synchronisation avec les actions du film. Des effets tels que le mouvement du siège, le vent, la pluie, les lumières et les odeurs permettent d’ajouter une autre dimension au film.

Les sièges vibrent en fonction de ce qui se passe à l’écran. Il y a sur les fauteuils des jets d’eau qui permettent de nous mouiller s’il pleut dans le film. Cette option peut être désactivée si l’utilisateur le souhaite. Il y a aussi des jets d’air, qui soufflent soit de l’air froid soit de l’air chaud. Ce système dispose également d’un diffuseur de parfum. Ce fauteuil est rempli de technologies, la sensation est donc garantie.

Les composants de ce siège sont donc :

- Un diffuseur de parfum

- Un vibreur
- Des brumisateurs
- Des boutons pour activer/désactiver des options
- Un système qui permet le déplacement du siège

Concernant les technologies déployées nous avons peu, voire aucune information à ce sujet.

On peut penser que l’une des techniques utilisées est l’intelligence artificielle, pour l’apprentissage du son afin de mieux reconnaître le son émis pour de meilleures vibrations. De même que pour l’apprentissage des images, qui permettrait d’émettre une odeur en fonction de l’image sur l’écran.

On peut aussi présumer qu’un système d’analyse d’image est utilisé pour savoir si on avance, monte, recule, descend ou bien tourne dans la vidéo.


XROCKER SONY INFINITI+

Le fauteuil XROCKER SONY INFINITI+ (sous licence officielle PlayStation) est un fauteuil
gamer spécialement conçu pour les systèmes de jeux PlayStation. (compatible avec PS vita,
PS3 et PS4). Ce fauteuil a été mis sur le marché en fin mars 2018. Il permet d’obtenir plus de sensations et d’augmenter l’immersion dans le jeu, ce qui changera notre manière de jouer.

Ce fauteuil est doté :

- Système audio 4.1
- 4 enceintes
- 1 subwoofer
- 3 moteurs de vibrations à détection sonore
- Connexion bluetooth
- Port USB
- Entrée jack
- Panneau de contrôle

Comme pour le fauteuil 4DX nous disposons de peu voire pas d’information sur les techniques utilisées on peut donc supposer que nous utilisons là aussi l’intelligence artificielle pour la reconnaissance du son.


Fauteuil vibrant Mod IT

Contrairement au fauteuil XROCKER SONY INFINITI+, le fauteuil vibrant MOD It est un fauteuil compatible avec les consoles mais il peut également se connecter au téléviseur par branchement ou bluetooth. Ce fauteuil possède donc un avantage en plus. Grace à ce fauteuil vous vous sentirez à la place du personnage avec une réelle impression 4D.

Ce fauteuil est lui aussi doté de :

- 2 haut-parleurs
- 1 subwoofer
- 1 module vibrant
- Bluetooth
- Bouton de réglage
- Jack
- USB

Concernant les techniques utilisées, nous trouvons peu d’information. Tout comme les modèles précédents, nous pensons aux mêmes techniques.

# Positionnement

## LEDs

Nous avons constaté que, dans toutes les analyses que nous avons menées concernant la LED les microprocesseurs utilisés sont ARDUINO et RASPBERRY PI. Nous avons aussi remarqué qu’il n’y avait pas de capteurs de lumière mais seulement un branchement filaire qui permet d’analyser l’image. Nous nous posons la question concernant l’utilisation du capteur (pour nous différencier des technologies déjà existantes) ainsi que sur le choix du microprocesseur.

## Housse vibrante

Concernant la housse vibrante, nous n’avons pas trouvé d’informations concernant les techniques utilisées. Nous avons donc fait des suppositions. Nous allons essayer de concevoir une housse vibrante en utilisant des vibrations et des hauts parleurs. Par contre nous ne savons pas s’il faut utiliser un capteur sonore puisque les sièges que nous avons trouvés ne possèdent pas de capteur. Nous devons donc mener une étude afin de voir les différentes possibilités qui s’offrent à nous et afin de faire le meilleur choix.

# Conclusion

D’après toutes nos analyses, nous avons pu constater un grand nombre de modèles existant dans les domaines que nous allons aborder. L’immersion à l’aide de LED et de vibrations dynamiques est une toute nouvelle façon d’interagir avec le consommateur. Les technologies sont telles qu’elles comportent encore énormément de brevets dus à la nécessité de longues recherches très coûteuses. Nous avons donc peu d’informations sur le domaine. La notion de capteur de lumière n’a pas été évoquée dans toutes nos analyses. C’est donc pour cela que nous allons étudier la faisabilité de l’intégration de celui-ci.

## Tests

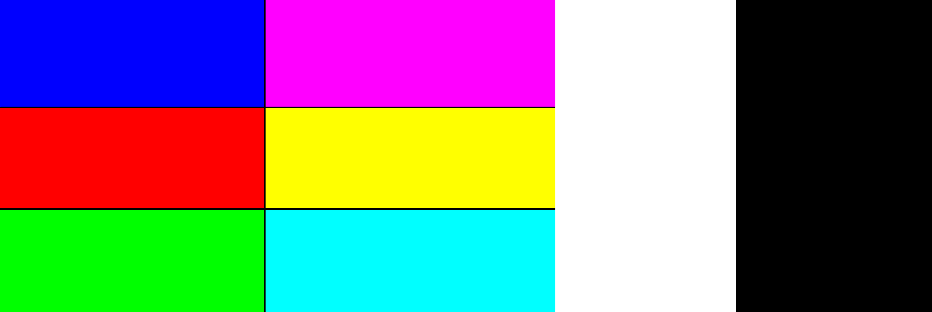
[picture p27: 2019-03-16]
Test Arduino/TCS3200/IMAGE TEST.png

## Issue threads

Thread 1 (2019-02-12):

Arduino ESP32 ?

Mohaabenz, 2019-02-12:
https://github.com/espressif/arduino-esp32/blob/master/docs/arduino-ide/windows.md
Cette methode est elle une alternative pour mettre le framework Arduino sur l'ESP32 ?

HamidiMassinissa, 2019-02-12:
Maybe it is suitable to share here the solution you find @Mohaabenz

Mohaabenz, 2019-02-12:
Voici la solution pour utilisé Arduino sur l’ESP32
https://randomnerdtutorials.com/installing-the-esp32-board-in-arduino-ide-mac-and-linux-instructions/

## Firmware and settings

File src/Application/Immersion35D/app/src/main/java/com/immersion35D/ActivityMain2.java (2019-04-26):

package com.immersion35D;

import android.annotation.SuppressLint;
import android.content.Intent;
import android.os.Bundle;
import android.support.v7.app.AppCompatActivity;
import android.view.View;
import android.widget.AdapterView;
import android.widget.ArrayAdapter;
import android.widget.Button;
import android.widget.SeekBar;
import android.widget.Spinner;
import android.widget.TextView;
import android.widget.Toast;

import java.io.IOException;

import static com.immersion35D.MainActivity.bSocket;

public class ActivityMain2 extends AppCompatActivity {

    //Valeur du rouge, vert, bleu et luminosité respectivement
    private int r, v, b, l;
    //Jauges pour la gestion du rouge, vert, bleu et de la luminosité respactivement
    private SeekBar sr, sv, sb, sl;
    //Affichage du rouge, vert, bleu et luminosité respectivement
    private TextView tr, tv, tb, tl;
    //


    String r1, v1, b1, l1, couleurs;
    //Menu des themes
    Spinner themes;
    Button retour;
    Button allumer;
    Button degrade;


    String etat = "A";


    @SuppressLint("SetTextI18n")
    @Override
    protected void onCreate(Bundle savedInstanceState) {
        super.onCreate(savedInstanceState);
        setContentView(R.layout.activity_main2);
        /*try {
            bluetooth_connect_device();
        } catch (IOException e) {
            e.printStackTrace();
        }*/
        // try {setw();} catch (Exception e) {}
        themes = findViewById(R.id.spinner);
        // Create an ArrayAdapter using the string array and a default spinner layout
        ArrayAdapter<CharSequence> adapter = ArrayAdapter.createFromResource(this, R.array.Theme, android.R.layout.simple_spinner_item);
        // Specify the layout to use when the list of choices appears
        adapter.setDropDownViewResource(android.R.layout.simple_spinner_dropdown_item);
        // Apply the adapter to the spinner
        themes.setAdapter(adapter);


        sr = findViewById(R.id.rouge);
        sv = findViewById(R.id.vert);
        sb = findViewById(R.id.bleu);
        sl = findViewById(R.id.luminosite);

        tr = findViewById(R.id.tr);
        tv = findViewById(R.id.tv);
        tb = findViewById(R.id.tb);
        tl = findViewById(R.id.tl);
        tr.setText(""+r+"");
        tv.setText(""+v+"");
        tb.setText(""+b+"");
        tl.setText(""+l+"");

        retour = findViewById(R.id.retour);
        allumer = findViewById(R.id.allumer);
        degrade = findViewById(R.id.degrade);

        themes.setOnItemSelectedListener(new AdapterView.OnItemSelectedListener() {
            @Override
            public void onItemSelected(AdapterView<?> parent, View view, int position, long id) {
                CharSequence themeSelectionne = (CharSequence) parent.getItemAtPosition(position);
                String s = themeSelectionne.toString();
                switch (s){
                    case "Blanc":
                        sr.setEnabled(true);
                        sv.setEnabled(true);
                        sb.setEnabled(true);
                        sl.setEnabled(true);
                        try {
                            bSocket.getOutputStream().write("T".getBytes());
                        } catch (IOException e) {
                            e.printStackTrace();
                        }
                        theme(128,128,128,50);
                        break;
                    case "Rouge":
                        sr.setEnabled(true);
                        sv.setEnabled(true);
                        sb.setEnabled(true);
                        sl.setEnabled(true);
                        try {
                            bSocket.getOutputStream().write("T".getBytes());
                        } catch (IOException e) {
                            e.printStackTrace();
                        }
                        theme(255,0,0,50);
                        break;
                    case "Vert":
                        sr.setEnabled(true);
                        sv.setEnabled(true);
                        sb.setEnabled(true);
                        sl.setEnabled(true);
                        try {
                            bSocket.getOutputStream().write("T".getBytes());
                        } catch (IOException e) {
                            e.printStackTrace();
                        }
                        theme(0,255,0,50);
                        break;
                    case "Bleu":
                        sr.setEnabled(true);
                        sv.setEnabled(true);
                        sb.setEnabled(true);
                        sl.setEnabled(true);
                        try {
                            bSocket.getOutputStream().write("T".getBytes());
                        } catch (IOException e) {
                            e.printStackTrace();
                        }
                        theme(0,0,255,50);
                        break;
                    case "Jaune":
                        sr.setEnabled(true);
                        sv.setEnabled(true);
                        sb.setEnabled(true);
                        sl.setEnabled(true);
                        try {
                            bSocket.getOutputStream().write("T".getBytes());
                        } catch (IOException e) {
                            e.printStackTrace();
                        }
                        theme(255,255,0,50);
                        break;
                    case "Magenta":
                        sr.setEnabled(true);
                        sv.setEnabled(true);
                        sb.setEnabled(true);
                        sl.setEnabled(true);
                        try {
                            bSocket.getOutputStream().write("T".getBytes());
                        } catch (IOException e) {
                            e.printStackTrace();
                        }
                        theme(255,0,255,50);
                        break;
                    case "Cyan":
                        sr.setEnabled(true);
                        sv.setEnabled(true);
                        sb.setEnabled(true);
                        sl.setEnabled(true);
                        try {
                            bSocket.getOutputStream().write("T".getBytes());
                        } catch (IOException e) {
                            e.printStackTrace();
                        }
                        theme(0,255,255,50);
                        break;
                    case "Orange":
                        sr.setEnabled(true);
                        sv.setEnabled(true);
                        sb.setEnabled(true);
                        sl.setEnabled(true);
                        try {
                            bSocket.getOutputStream().write("T".getBytes());
                        } catch (IOException e) {
                            e.printStackTrace();
                        }
                        theme(255,50,0,50);
                        break;
                    case "Rose":
                        sr.setEnabled(true);
                        sv.setEnabled(true);
                        sb.setEnabled(true);
                        sl.setEnabled(true);
                        try {
                            bSocket.getOutputStream().write("T".getBytes());
                        } catch (IOException e) {
                            e.printStackTrace();
                        }
                        theme(255,0,40,50);
                        break;
                    case "Guirelande":
                        sr.setEnabled(false);
                        sv.setEnabled(false);
                        sb.setEnabled(false);
                        sl.setEnabled(false);
                        try {
                            bSocket.getOutputStream().write("G".getBytes());
                        } catch (IOException e) {
                            e.printStackTrace();
                        }
                        break;
                    case "Fondu":
                        sr.setEnabled(false);
                        sv.setEnabled(false);
                        sb.setEnabled(false);
                        sl.setEnabled(true);
                        try {
                            bSocket.getOutputStream().write("F".getBytes());
                        } catch (IOException e) {
                            e.printStackTrace();
                        }
                        break;
                }
                etat = "A";
                for (int i=1; i<=4; i++)
                {
                    envoiCouleurs(i);
                }
            }

            @Override
            public void onNothingSelected(AdapterView<?> parent) {

            }
        });

        //Gestion de l'affichage des valeurs en instantané

        sr.setOnSeekBarChangeListener(new SeekBar.OnSeekBarChangeListener() {
            @Override
            public void onProgressChanged(SeekBar seekBar, int progress, boolean fromUser) {
                r1="r"+progress+";";
                r = progress;
                tr.setText(""+progress+"");
                etat = "A";
                envoiCouleurs(1);
            }

            @Override
            public void onStartTrackingTouch(SeekBar seekBar) {

            }

            @Override
            public void onStopTrackingTouch(SeekBar seekBar) {

            }
        });

        sv.setOnSeekBarChangeListener(new SeekBar.OnSeekBarChangeListener() {
            @Override
            public void onProgressChanged(SeekBar seekBar, int progress, boolean fromUser) {
                v1="v"+progress+";";
                v = progress;
                tv.setText(""+progress+"");
                etat = "A";
                envoiCouleurs(2);
            }

            @Override
            public void onStartTrackingTouch(SeekBar seekBar) {

            }

            @Override
            public void onStopTrackingTouch(SeekBar seekBar) {

            }
        });

        sb.setOnSeekBarChangeListener(new SeekBar.OnSeekBarChangeListener() {
            @Override
            public void onProgressChanged(SeekBar seekBar, int progress, boolean fromUser) {
                b1="b"+progress+";";
                b = progress;
                tb.setText(""+progress+"");
                etat = "A";
                envoiCouleurs(3);
            }

            @Override
            public void onStartTrackingTouch(SeekBar seekBar) {

            }

            @Override
            public void onStopTrackingTouch(SeekBar seekBar) {

            }
        });

        sl.setOnSeekBarChangeListener(new SeekBar.OnSeekBarChangeListener() {
            @Override
            public void onProgressChanged(SeekBar seekBar, int progress, boolean fromUser) {
                l1="l"+progress+";";
                l = progress;
                tl.setText(""+progress+"");
                etat = "A";
                envoiCouleurs(4);
            }

            @Override
            public void onStartTrackingTouch(SeekBar seekBar) {

            }

            @Override
            public void onStopTrackingTouch(SeekBar seekBar) {

            }
        });

        retour.setOnClickListener(new View.OnClickListener() {
            @Override
            public void onClick(View v) {
                Intent ActivityMain4 = new Intent(getApplicationContext(), ActivityMain4.class);
                startActivity(ActivityMain4);
                finish();
            }
        });

        allumer.setOnClickListener(new View.OnClickListener() {
            @Override
            public void onClick(View v) {
                onOff();
            }
        });

        degrade.setOnClickListener(new View.OnClickListener() {
            @Override
            public void onClick(View v) {
                try {
                    bSocket.getOutputStream().write("D".getBytes());
                } catch (IOException e) {
                    e.printStackTrace();
                }
                Intent ActivityMain5 = new Intent(getApplicationContext(), ActivityMain5.class);
                startActivity(ActivityMain5);
                finish();
            }
        });


    }

    @SuppressLint("HardwareIds")
    private void envoiCouleurs(int a)
    {
        try
        {
            if (bSocket!=null)
            {
                if(a==1) {
                    couleurs = r1;
                    for (char e : couleurs.toCharArray()) {
                        bSocket.getOutputStream().write(e);
                    }
                }
                if(a==2) {
                    couleurs = v1;
                    for (char e : couleurs.toCharArray()) {
                        bSocket.getOutputStream().write(e);
                    }
                }
                if(a==3) {
                    couleurs = b1;
                    for (char e : couleurs.toCharArray()) {
                        bSocket.getOutputStream().write(e);
                    }
                }
                if(a==4) {
                    couleurs = l1;
                    for (char e : couleurs.toCharArray()) {
                        bSocket.getOutputStream().write(e);
                    }
                }
                // btSocket.getOutputStream().write(this.r);
            }
        }
        catch (Exception e)
        {
            Toast.makeText(getApplicationContext(),e.getMessage(), Toast.LENGTH_SHORT).show();
        }
    }

    private void onOff()
    {
        try
        {
            if (bSocket!=null)
            {
                if (etat.equals("E")) {
                    etat = "A";
                }
                else if (etat.equals("A")){
                    etat = "E";
                }
                bSocket.getOutputStream().write(etat.getBytes());
            }
        }
        catch (Exception e)
        {
            Toast.makeText(getApplicationContext(),e.getMessage(), Toast.LENGTH_SHORT).show();
        }
    }

    public void theme(int rd,int vt,int be, int lm){
        this.r = rd;
        this.r1= ""+this.r;
        this.v = vt;
        this.v1= ""+this.v;
        this.b = be;
        this.b1= ""+this.b;
        this.l = lm;
        this.l1= ""+this.l;
        sr.setProgress(this.r);
        sv.setProgress(this.v);
        sb.setProgress(this.b);
        sl.setProgress(this.l);

    }


}

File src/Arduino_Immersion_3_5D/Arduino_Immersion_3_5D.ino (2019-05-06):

#include <Adafruit_NeoPixel.h>
#include <SoftwareSerial.h>
#include <stdlib.h>
#include <TCS3200.h>
#define BLED 12
#define LED 13
#define OFF 0
#define CALIBRAGE 1
#define IMMERSION 2
#define THEME 3
#define GUIRELAND 4
#define FONDU 5
#define DEGRADER 6

Adafruit_NeoPixel strip = Adafruit_NeoPixel(60, BLED, NEO_GRB + NEO_KHZ800);
// CS ( S2, S3, OUT, S0, S1, LED )
TCS3200 CS(4, 3, 2, 6, 5, 13);
char r = NULL;
int n, b;
int i = 0;
int k = 0;
int rvb[4] = {0, 0, 0, 200};
int dge[4] = {0, 0, 0, 50};
char buf;

int mode = OFF;
colorData current;
colorData *data;

/////////////////////////////Fonction Principale//////////////////////////////

void setup()
{
  Serial.begin(9600);
  CS.begin();
  CS.LEDON(false);
  strip.begin();
  randomSeed(1996);
}

void loop()
{
  if (mode == OFF)
    onOff();
  if (mode == CALIBRAGE)
    cali();
  if (mode == IMMERSION)
    immersion_3_5_D();
  if (mode == THEME)
    control_Color();
  if (mode == GUIRELAND)
    guireland();
  if (mode == FONDU)
    fondu();
  if (mode == DEGRADER)
    degrader();
}

/////////////////////////////Detection du mode courant///////////////////////////////////
void getMode(){
   if (Serial.available())
  {
    buf = (char)Serial.read();
    
    if (buf == 'C') {
      mode = CALIBRAGE;

    }
    if (buf == 'G'){
      mode = GUIRELAND;
    }
    if (buf == 'I') {
      mode = IMMERSION;
    }
    if (buf == 'F'){
      mode = FONDU;
    }
    if (buf == 'D'){
      mode = DEGRADER;
    }
    if (buf == 'T') {
      mode = THEME;
    }
     if (buf == 'A') {
      for (int j = 0; j < 60; j++)
      {
        strip.setPixelColor(j, rvb[0], rvb[1], rvb[2]);
      }
      strip.show();
    }
    if (buf == 'E') {
      for (int j = 0; j < 60; j++)
      {
        strip.setPixelColor(j, 0, 0, 0);
      }
      strip.show();
    }
  }
}

//////////////////////////Fonction Allumer/Eteindre////////////////////////////////
void onOff() {
  if (Serial.available() && mode == OFF)
  {
    buf = (char)Serial.read();
     Serial.println(buf);
    if (buf == 'A') {
      for (int j = 0; j < 60; j++)
      {
        strip.setPixelColor(j, 255, 255, 255);
      }
      strip.show();
    }
    if (buf == 'E') {
      for (int j = 0; j < 60; j++)
      {
        strip.setPixelColor(j, 0, 0, 0);
      }
      strip.show();
      mode = OFF;
    }
    if (buf == 'T') {
      mode = THEME;
    }
    if (buf == 'C') {
      mode = CALIBRAGE;
    }
    if (buf == 'I') {
      mode = IMMERSION;
    }
    if (buf == 'G') {
      mode = GUIRELAND;
    }
    if (buf == 'F'){
      mode = FONDU;
    }
    if (buf == 'D')
      mode = DEGRADER;
  }
}


///////////////////////////////////Fonction du Capteur////////////////////////////////////

void cali() {
  bool done = false;
  delay(75);
  Serial.println("Voulez vous calibrer le capteur : ");
   Serial.println("Oui pour commencer, Mode Immersion pour quitter");
  while (!done)
  {
    if (Serial.available())
    {
      r = Serial.read();
      delay(10);

      if (r == 'O')
      {
        CS.loadCal(0);
        done = true;
      }
      if (r == 'Y')
      {
        calibrage();
        done = true;
      }
      Serial.flush();
    }
  }
  mode = IMMERSION;
}

void calibrage()
{
  Serial.println("Debut du calibrage !!");
  CS.nSamples(40);
  CS.setRefreshTime(200);
  CS.setFrequency(TCS3200_FREQ_HI);
  CS.calibration(0);
}

////////////////////Fonction automatique d'immersion/////////////////////////
void immersion_3_5_D()
{
  getMode();
  current = CS.readRGB();
  CS.getRGB(&current);

  for (int j = 0; j < 60; j++)
  {
    strip.setPixelColor(j, current.value[0], current.value[1], current.value[2]);
  }
  strip.show();
}

//////////////////////Controle des couleurs de la bande LED///////////////////////////
void control_Color()
{
  while (Serial.available() && mode == THEME)
  {
    getMode();

    if (buf == 'r') {
      i = 0;
      n = 2;
      rvb[i] = 0;
    }

    if (buf == 'v') {
      i = 1;
      n = 2;
      rvb[i] = 0;
    }
    if (buf == 'b') {
      i = 2;
      n = 2;
      rvb[i] = 0;
    }
    if (buf == 'l') {
      i = 3;
      n = 2;
    }
    if (buf == ';') {
      rvb[i] = rvb[i] / coef(n + 1);
      for (int j = 0; j < 60; j++)
      {
        strip.setPixelColor(j, rvb[0], rvb[1], rvb[2]);
      }
      strip.setBrightness(rvb[3]);
      strip.show();
      delay(20);
      Serial.flush();
    }
    if (charToInt(buf) != -1) {
      b = charToInt(buf);
      rvb[i] += b * coef(n);
      n--;
    }
  }
}

////////////////////////////////Different mode de la bande LED//////////////////////////////

////////Mode Guireland///////////
void guireland()
{
  getMode();
  while(Serial.available()>0)
  {
    char trash = Serial.read();
  }
  Serial.println(buf);
  if(!(buf == 'E')){
  for (int j = 0; j < 60; j++)
  {
    strip.setPixelColor(j, random(j), random(j + 1), random(j + 2));
  }
  strip.show();
  delay(400);
  }
}

////////////Mode Fondu////////////
void fondu()
{
  getMode();
  strip.setBrightness(rvb[3]);
  increaseGreen();
  increaseBlue();
  decreaseGreen();
  increaseRed();
  decreaseBlue();
  increaseGreen();
  increaseBlue();
  decreaseBlue();
  decreaseGreen();
  decreaseRed();
  delay(25); 
}

///////////Mode Degrader///////////
void degrader()
{
  while (Serial.available() && mode == DEGRADER)
  {
    getMode();

    if (buf == 'r') {
      i = 0;
      k = 1;
      n = 2;
      rvb[i] = 0;
    }

    if (buf == 'v') {
      i = 1;
      k = 1;
      n = 2;
      rvb[i] = 0;
    }
    if (buf == 'b') {
      i = 2;
      k = 1;
      n = 2;
      rvb[i] = 0;
    }
    
    if (buf == 'd') {
      i = 0;
      k = 2;
      n = 2;
      dge[i] = 0;
    }

    if (buf == 'g') {
      i = 1;
      k = 2;
      n = 2;
      dge[i] = 0;
    }
    if (buf == 'e') {
      i = 2;
      k = 2;
      n = 2;
      dge[i] = 0;
    }

    if (buf == 'l') {
      i = 3;
      k = 1;
      n = 2;
    }
    
    if (buf == ';') {
      if(k == 1)
        rvb[i] = rvb[i] / coef(n + 1);
      if(k == 2)
        dge[i] = dge[i] / coef(n+1);
      for (int j = 0; j < 60; j++)
      {
        strip.setPixelColor(j, (60-j)*rvb[0]/60 + j*dge[0]/60, (60-j)*rvb[1]/60 + j*dge[1]/60 , (60-j)*rvb[2]/60 + j*dge[2]/60);
      }
      //strip.setPixelColor(0,rvb[0],rvb[1],rvb[2]);
      //strip.setPixelColor(1,dge[0],dge[1],dge[2]);
      strip.setBrightness(rvb[3]);
      strip.show();
      delay(20);
      Serial.flush();
    }
    if (charToInt(buf) != -1) {
      b = charToInt(buf);
      if(k==1)
        rvb[i] += b * coef(n);
      if(k==2)
        dge[i] += b * coef(n);
      n--;
    }
  }
}

/////////////////////////////////Fonction auxilliaire pour degrader/////////////////////////////////////
void increaseRed(){
  while(rvb[0] <255 && mode == FONDU){
    getMode();
    for (int j = 0; j < 60; j++)
    {
      strip.setPixelColor(j, rvb[0],rvb[1], rvb[2]);
    }
    strip.show();
    delay(25);
    rvb[0]++;
  }
}
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

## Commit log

2019-02-19 Cahier des Charges Immersion 3.5D
2019-02-26 Etude de l'existant
2019-03-08 Changement de nom
2019-03-12 Image Test et Montage
    Sauvegarde du montage de la TCS3200
    Image Test Couleur Primaire
2019-03-13 Détection de périphériques bluetooth
2019-03-19 MAJ CAPTEUR ET ACHAT LED
2019-03-19 Calibrage
    meilleur detection des couleur a l'écran
2019-03-20 Implémentation des thèmes
2019-03-26 Ajout d'un code de bluethooth basique
    code basique d'un module bluethooth en utilisant seulement les pin RX et TX
2019-03-26 TEST BANDE LED + TCS
2019-03-27 BT Android led
2019-04-02 Led control V2
2019-04-09 Debut du merge de code
2019-04-13 Update code arduino
2019-04-23 Correction de guireland
2019-04-24 Schéma Fritzing
    Le TCS3200 est introuvable sur internet, je sais pas comment créé un nouveau morceau de schéma, j'ai utiliser un autre morceau qui ne correspond pas entiérement, j'ai du faire des branchement qui peu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
    [IP35D.fzz]
2019-04-24 Mise a jour des schéma
    j'ai trouver un schéma de TCS3200 qui correspond plus a ce qu'on as
    [IP35D.fzz]
2019-04-25 Application Name
    [buttonshape.xml, buttonshape2.xml, buttonshape3.xml]
2019-04-26 Maquette et structure du code Arduino
2019-04-30 Correction des fautes d'orthographe
2019-05-02 Correction orthographe partie de Khalid
    La phrase en rouge il faut la reformuler
2019-05-06 PowerPoint fini
2019-05-06 Structure GitHub
    [IP35D.fzz]
2019-05-06 Structure + Video
    [buttonshape.xml, buttonshape2.xml, buttonshape3.xml]
